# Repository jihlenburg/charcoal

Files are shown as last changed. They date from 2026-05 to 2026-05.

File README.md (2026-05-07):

# Aktivkohlefilter-Einsatz (Passivlüftung mit aktiven Absaugungen)

**Version: 1.1.6**. Der String steht im Script als `VERSION`-Konstante und
wird als Gravur auf den +Y-Flanschüberstand übernommen. Bei jedem Versionssprung
muss er gleichzeitig in `carbon_filter_build123d.py`, im README und am
git-Tag nachgezogen werden.

Parametrischer Filterkorb aus Grundkörper und Deckel für die Wohnungs­lüftung
mit Aktivkohle. Die Konstruktion ist für HP Multi Jet Fusion in **PA12**
ausgelegt (`HP 3D HR PA 12 enabled by Evonik` oder vergleichbar). PA11 ist
nach wie vor eine tolerantere Alternative, aber nicht mehr der Konstruktionsfall.

Quellcode: [`carbon_filter_build123d.py`](./carbon_filter_build123d.py) (build123d).

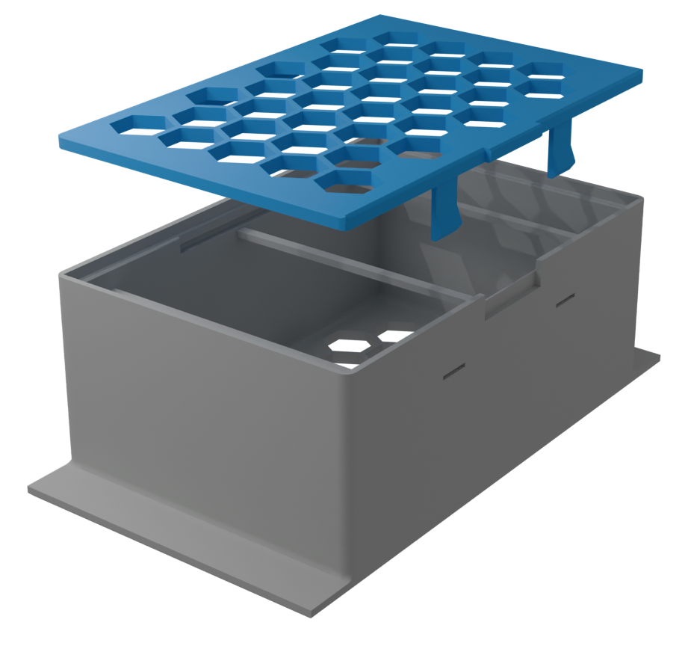
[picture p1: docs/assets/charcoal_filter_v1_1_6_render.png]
Exploded render of the filter cassette


Das README-Render entsteht über `./run render-readme` (Blender/Cycles, mit
VTK-Fallback, falls Blender fehlt).

## Konstruktionsprinzip

**Vertikaler Luftstrom durch den Filter.** Die Luft tritt durch das Hex-Gitter
auf der einen Z-Seite (Deckel) ein, durchströmt das Aktivkohlebett und
verlässt die Kassette durch das Hex-Gitter auf der anderen Z-Seite (Boden).
Im Skript-Koordinatensystem ist Z die Luftstromachse — eingebaut steht die
Kassette um 90° gekippt, sodass Z horizontal zur Schachttiefe wird.

### Befüllung (Kassette stehend, Deckel oben)

1. Finger in die mittige Freistellung an der Schnapper-Seite setzen und den
   Deckel am kleinen Zugsteg nach oben anheben. Die beiden Schnapper lösen
   sich dabei über ihre Auslöserampe selbsttätig; auf der Gegenseite hält die
   Hakenleiste den Deckel in ihrer Tasche und gibt damit die Öffnungs­seite vor
2. Filtervlies auf den Boden legen (3 mm, dichtet Hex gegen Granulatdurchfall)
3. Aktivkohlegranulat einfüllen (~29 mm Schüttung, ~72 g bei 450 kg/m³)
4. Zweites Filtervlies obenauf; die internen Anti-Bauch-Bars liegen 4.0 mm
   unter der Deckelunterseite, sodass ein 3-mm-Vlies mit ca. 1 mm Reserve
   zwischen Bars und Deckel passt
5. Deckel erst mit der Hakenleiste in die Gegentasche einsetzen, dann die
   Schnapper-Seite herunterdrücken bis beide Nasen hörbar einrasten

## Einbaukontext

Der Schacht am Fensterrahmen hat 70 mm harte Innenbreite (mit je ca. 5 mm
Schaumstoff an beiden Seiten → 80 mm weich), 100 mm harte Höhe und 100 mm
Tiefe. Luftrichtung: hinten → vorne, angetrieben von drei aktiven
Wohnungs­absaugungen (3 Fenster × 2 Schächte = 6 parallele Zuluftpfade).

**Einbaulage (wichtig)**: Die Kassette wird mit dem **Deckel nach hinten**
eingeschoben, der **Boden zeigt nach vorne** in die Wohnung. Gründe:

- Der Y-Flanschüberstand (je 10 mm oben und unten) ist der Fingergriff.
  Beim Ziehen kommt immer die gesamte Kassette mit — nie nur der Deckel.
- Der Luftstrom drückt den Deckel in seinen Sitz, nicht heraus.
- Der Flansch am Boden fungiert als **Einschub-Stopper und Fingergriff**.
  Er ragt **nur in Y-Richtung** (vertikal im Schacht) über den Körper
  hinaus — in X bleibt er auf Körperbreite, weil die harte Schachtbreite
  70 mm nicht überschritten werden darf. Flansch-Footprint: 65 × 115 mm vs.
  Schacht-Hartöffnung 70 × 100 mm — die je 10 mm-Überstände oben und unten
  fangen an der Schacht-Frontkante und geben gleichzeitig bequem Platz für
  Daumen/Zeigefinger. Die Kassette steht damit `floor = 2.2 mm` aus der
  Öffnung heraus — klar unter der 5-mm-Grenze.

### Abdichtung mit Moosgummi

Die Y-Flächen der Kassette — im Skript-Frame oben und unten — kontaktieren
im Schacht die **harten** oberen und unteren Schachtwände. Sie sind dafür
glatt und ohne Durchbrüche ausgeführt. Vor dem Einschub werden auf beide
Flächen **Moosgummistreifen** geklebt; beim Einschieben werden sie
zusammengepresst und dichten dadurch axial gegen Leckluft am Filterbett vorbei.

Auf der einen X-Fläche sitzen die Snap-Durchbrüche, gegenüber eine flache
Haken-Tasche im oberen Wandbereich. Beide X-Flächen drücken sich in den
seitlichen Schaumstoff und werden so durch den Schaum selbst abgedichtet.

## Geometrie

- Zwei Teile: Grundkörper (Trog mit integriertem Flansch + Boden) und Deckel
- Körper-Aussenmasse: **65 (X) × 95 (Y) × 40 (Z)** mm
- Bodenflansch: **65 × 115 × 2.2** mm (Z = 0 … 2.2) — nur in Y breiter als Körper
  (je 10 mm Überstand oben und unten als Stopper + Fingergriff)
- Wand 2.2 mm, Boden 2.2 mm, Deckel 2.5 mm
- Hex-Perforation identisch auf **Boden** und **Deckel** (Z-Flächen):
  10 mm flat-to-flat, 1.2 mm Stegbreite, 2.8 mm X-Randabstand und 4.0 mm
  Y-Randabstand → 36 Löcher pro Fläche, ~57 % Offenfläche
  (~31 cm² auf ~55 cm² Kavität)
- Rabbet-Sitz am oberen Rand, 1.0 mm Schulter, 2.5 mm tief
- Passungsspiel 0.30 mm pro Seite (MJF-Standard)
- Kein Fingerausschnitt am Boden — die 10 mm Y-Flansch-Überstände oben und
  unten dienen als Fingergriff (Daumen oben, Zeigefinger unten, ziehen)
- Aktivkohlebett-Tiefe: **29.3 mm** (= Z − Boden − Deckel − 2 × 3 mm Filtervlies)
- Drei interne Anti-Bauch-Bars verbinden die langen X-Wände bei
  `Y = -36, 0, +36 mm`. Je Bar: **2.2 mm** breit in Y, **1.4 mm** hoch in Z,
  quer über die Kavität. Lage: **Z = 32.1 … 33.5 mm**, damit zur
  Deckelunterseite bei `Z = 37.5 mm` ein **4.0 mm** Spalt für das obere
  3-mm-Filtervlies bleibt.

### Versionsgravur

Der `VERSION`-String aus dem Script wird als 0.6 mm tiefe Vertiefung
(Font-Size 5 mm) auf die **Apartment-seitige Fläche des +Y-Flansch­überstands**
graviert. Position: Z = 0 … 0.6 mm, vertikal zentriert auf der Mittellinie des
10 mm breiten Überstands. Die Stelle ist solid (keine Hex-Löcher, keine
Snap-Schlitze), in der Sichtlinie des Benutzers, und die 1.6 mm Restboden
unter der Gravur liegt komfortabel über dem MJF-Minimum von 1.0 mm.

Die Gravur-Ebene ist bewusst gespiegelt konstruiert (Plane mit `z_dir=-Z`
und `x_dir=-X`, sodass `y_dir=+Y` rechtshändig bleibt), damit der Text von
der Apartment-Seite aus korrekt lesbar ist — aus −Z-Blickrichtung wäre ein
Standard-Plane.XY-Sketch nämlich spiegelverkehrt dargestellt.

Beim Versionswechsel muss die `VERSION`-Konstante im Script-Header **und**
die Angabe oben im README synchron nachgezogen werden (plus git-Tag beim
Release).

### Deckel und Schnappverbindung

- Deckel 2.5 mm dick, Oberseite bündig mit der Trog-Oberkante
- Asymmetrische Verriegelung: **eine** passive Hakenleiste auf einer X-Seite,
  **zwei** Cantilever-Rastnasen auf der gegenüberliegenden X-Seite.
- Passive Hakenleiste: 34 mm lang, 3 mm Absenkung, als **einfache**
  Hakenleiste mit 2.1 mm Gesamttiefe, 1.0 mm starkem oberem Steg und einer
  0.35 mm über die Deckelkante nach außen gezogenen Nase. Die reale
  Überdeckung hinter der Trog-Innenwand steigt damit auf etwa **1.05 mm**.
  Sie greift in eine flache rechteckige Tasche in der Gegenseite. Die Tasche
  ist zweistufig: unten eine 1.35 mm tiefe Retentionstasche, oben nur ein
  0.55 mm tiefer Einführkanal. Dadurch bleibt über der unteren Tasche eine
  **0.80 mm** tiefe Material-Lippe, unter der die Haken-Nase sichtbar trägt.
  Außen bleiben etwa **0.30 mm** Taschenluft. Die äußerste Haken-Nase ist mit
  einer 0.2-mm-Fase entschärft.
- Keine passiven Eckfreistiche mehr: die `v1.1.0`-Reliefs haben auf den
  Druckteilen eine sichtbare Diagonalkante erzeugt. `v1.1.6` entfernt diese
  kosmetische Störkante wieder; die zweistufige Haken-Tasche bleibt im
  Baugruppen-Checker trotzdem kollisionsfrei.
- Rastnasen: 6 mm breit, 10.2 mm lang, 1.0 mm Armdicke, 1.1 mm
  Lippenüberstand, 1.5 mm Einführschräge, 0.4 mm Haltelänge, 2.8 mm
  Auslöserampe, 0.5 mm Armwurzel-Fillet.
- Auf der Schnapper-Seite sitzt mittig eine kleine Zuglippe; die Trogwand hat
  dort eine Freistellung, die bewusst noch 1.0 mm Restwand stehen lässt,
  sodass der Deckel nach dem Entriegeln gezielt angehoben werden kann.
- Vorteile:
  - Klare passive Halteseite statt bloßer Führung
  - Deutlich einfacher als ein tiefes verstecktes Haken-/Taschensystem
  - Toleranzfreundlicher als 4 aktive Schnapper
  - Reversibel mit **einer** Hebebewegung: Zuglippe anheben, Schnapper
    cammen selbsttätig frei, Deckel klappt an der Haken-Seite kontrolliert hoch

### Variantenvergleich

- **Nur Führungsleiste**: sehr einfach und für MJF gut druckbar, aber
  ohne passive Haltefunktion. Die Gegenseite positioniert nur, sie trägt
  keinen Aufwärtslastpfad.
- **Einfache Hakenleiste**: der beste Kompromiss. Ein echter Formschluss auf
  einer Seite, dabei aber nur eine flache, gut entpulverbare Tasche mit
  kleiner Überdeckung.
- **Tiefes Haken-/Taschensystem**: mechanisch eindeutig, aber unnötig komplex,
  toleranzempfindlicher und für diesen Anwendungsfall überdimensioniert.

### Öffnungsbewegung und Kraftfluss

Im geschlossenen Zustand greifen auf der Schnapper-Seite die beiden Rastlippen
über die Oberkante der Slots, und auf der Gegenseite sitzt die einfache
Hakenleiste mit etwa `1.1 mm` Überdeckung unter dem Taschendach. Ein
Aufwärtszug am Deckel verteilt sich deshalb nicht nur auf die Schnapper,
sondern wird als Moment zwischen Schnapper- und Hakenseite aufgenommen.

Das Öffnen beginnt an der mittigen Zuglippe auf der Schnapper-Seite. Die
Fingerkraft erzeugt dort ein Drehmoment um die passive Hakenseite, und die
oberen Auslöserampen der Schnapper laufen gegen die Slot-Kante. Aus dem
vertikalen Hub wird dadurch eine seitliche Arm-Auslenkung; die Reaktions­kraft
fließt vom Finger über den Deckel in die Schnapper und von dort in die
Trogwand der Slot-Seite.

Sobald die Schnapper ausgelöst haben, sind sie weitgehend lastfrei. Den Rest
des Öffnungsmoments übernimmt die passive Hakenseite: der Deckel klappt um
sie hoch, statt auf beiden Seiten gleichzeitig lose zu werden. Zum
vollständigen Abnehmen wird er nach dem Hochklappen leicht zur Schnapper-Seite
verschoben, sodass der passive Haken aus seiner Tasche frei kommt — erst dann
lässt er sich nach oben abheben.

### Öffnungskraft / Werkzeugfreiheit

Für die Rastarme wird der Deckel als rechteckiger Cantilever abgeschätzt.
Die reine Armsteifigkeit liefert die laterale Federkraft; die tatsächliche
Fingerkraft beim Öffnen sinkt durch die obere Auslöserampe:

```
F = 3 · E · I · δ / L³
I = b · t³ / 12
```

mit `b = 6 mm`, `t = 1 mm`, `L = 10.2 mm`, `δ = hook_protr + fit_clear = 1.4 mm`
und einem HP-PA12-Elastizitätsmodul von grob `E ≈ 1.65 … 2.20 GPa`
(JF 5200/5600-Datenblattband).

Ergebnis:

- laterale Federkraft pro Schnapper: **ca. 3.3 … 4.4 N**
- geschätzte Finger-Hebekraft gesamt: **ca. 3.3 … 4.4 N**
  für beide Schnapper zusammen, mit 2.8-mm-Auslöserampe und einer groben
  Reibannahme `μ ≈ 0.2`
- Maximale Randfaserdehnung: **≈ 2.02 %**

Damit ist die Bedienung realistisch **ohne Werkzeug** und mit einer einzigen
Fingerbewegung. Die Schnapper müssen nicht separat gedrückt werden; beim
Anheben an der Zuglippe fahren sie über die Auslöserampe selbst nach innen.

HPs Snap-Fit-Handbook gibt als grobe Faustregel eine zulässige Dehnung
unter `1/3` der Fließdehnung an. Mit HP-PA12 (`~9 … 11 %` Fließdehnung laut
5600-Datenblatt) liegt der Zielbereich damit bei `< 3.0 … 3.7 %`; die
aktuellen `~2.02 %` bleiben deutlich darunter. Bei nur wenigen Öffnungs­zyklen
pro Jahr ist das für PA12 weit plausibler als die ältere kurze 7-mm-Geometrie.

### Lokale FEM des Schnappers

Zur Balkenabschätzung kommt eine lokale 3D-FE-Analyse in
`fem/snap_fit_fem.py` dazu. Das Modell bildet **einen aktiven Schnapper** in
der aktuellen `v1.1.6`-Nasenform ab, belastet die reale Rastfläche mit
`1 N` in `+X` und skaliert die Antwort anschließend auf die nötige
Öffnungs-Auslenkung `hook_protr + fit_clear = 1.40 mm`.

Drei Vorbehalte zum Mitlesen:

- Es ist bewusst nur ein **lokales Submodell**, kein vollständiges
  Kontaktmodell aus Deckel, Trog und Gegenhaken.
- Die FE-Kraft fällt **konservativer** aus als die Balkenformel, weil die
  Last an der realen Rastfläche bei `z ≈ -8.5 mm` ansetzt, nicht am freien
  Armende.
- Der `0.5 mm`-Armradius an der Deckelwurzel ist in diesem ersten Modell
  noch nicht explizit vernetzt; die echte Spitzendehnung dürfte deshalb
  leicht niedriger liegen.

Aktueller Stand mit `mesh_size = 0.25 mm` und nominalem `E = 2150 MPa`:

- laterale Federsteifigkeit pro Schnapper: **~7.3 N/mm**
- nötige laterale Auslenkkraft pro Schnapper für `1.40 mm`: **~10.3 N**
- geschätzte Gesamt-Hebekraft zum Öffnen: **~8.0 … 10.6 N**
- maximale Hauptdehnung beim Öffnen: **~3.4 %**

Werkzeugloses Öffnen bleibt damit plausibel. Wiederholtes Öffnen liegt im
HP-`1/3`-Proxyband für PA12 (`< 3.0 … 3.7 %`), aber mit kleinerer Reserve,
als die reine Balkenformel vermuten lässt.

### Lokale FEM der passiven Hakenleiste

Für die passive Hakenleiste gibt es das Pendant-Modell `fem/hook_hold_fem.py`.
Es belastet den unteren Hakennasenbereich mit `1 N` nach unten, klemmt den
oberen Steg als Deckelanschluss ein und skaliert die lineare Elastizität bis
zum PA12-`1/3`-Proxyband hoch.

Aktueller Befund für `v1.1.6`:

- reale Überdeckung hinter der Trog-Innenwand: **1.05 mm**
- nötige bewusste `+X`-Verschiebung zum Aushängen: **~1.05 mm**
- äußere Taschenluft: **0.30 mm**
- Retentionslippe in der Trogwand: **0.80 mm** tiefer Materialüberhang
- oberer Hakensteg: **1.00 mm** stark, **34 mm²** Querschnitt
- vertikale lokale Steifigkeit der Hakenleiste: **~1027 N/mm**
- PA12-`1/3`-Proxy-Haltekraft strukturell: **~174 … 213 N**

Interpretation: Nicht die PA12-Festigkeit der Hakenleiste war der begrenzende
Faktor, sondern ihre Geometrie. `v1.1.3` hatte real nur etwa `0.70 mm`
Untergriff und einen mit `0.40 mm` zu dünnen oberen Hakensteg. Ab `v1.1.5`
ist der Untergriff vergrößert, der Haken selbst sauberer druckbar und in der
Trogwand sitzt eine sichtbare Retentionslippe.

### Innenaufbau (Luftweg-Richtung: Deckel → Boden)

```
Hex-Deckel → 3 mm Filtervlies → Anti-Bauch-Bars / Aktivkohlebett (~29 mm) → 3 mm Filtervlies → Hex-Boden
```

Das Bett sitzt zwischen zwei Vlieslagen; sie halten die Pellets zurück und
fangen gleichzeitig Staub ab. Die Anti-Bauch-Bars liegen unter dem oberen
Vlies und halten die langen Seitenwände beim Befüllen davon ab, sich nach
außen zu biegen.

## Nutzung

Die Python-Umgebung wird über `./run` automatisch als lokale `.venv/`
angelegt und aus `requirements.txt` aktualisiert, sobald sich die
Abhängigkeiten ändern. Der Wrapper wählt automatisch eine kompatible
Python-Version im Bereich 3.9–3.12, weil die CAD/OCP-Native-Wheels nicht für
jede neueste Python-Version verfügbar sind:

```bash
./run setup
```

1. VSCode öffnen, Command Palette → „OCP CAD Viewer: Open Viewer"
2. `./run cad` ausführen
3. Viewer-Panel: Maus zum Drehen, Scroll zum Zoomen

Datei speichern triggert Live-Reload im Viewer. Beim Ausführen werden
automatisch die Exporte in `output/STEP/` (für STEP) und `output/STL/`
(für STL) geschrieben — je eine `trough.*` und `lid.*` Datei.

`EXPLODED = True` hebt den Deckel 30 mm über den Trog; für die
Zusammenbau-Ansicht auf `False` setzen.

Für manuelle Python-/Pip-Kommandos innerhalb derselben Umgebung:

```bash
./run python --version
./run pip list
./run shell
```

### Konsistenz-Check Script ↔ README

Die geometrischen Konstanten (Außenmaße, Wandstärken, Hex-Raster,
Anti-Bauch-Bars, Snap- und Hook-Maße) und der `VERSION`-String stehen doppelt
im Repo: einmal als Variablen im Script, einmal als Prosa- und Tabellenwerte
in diesem README. Damit beide nicht auseinanderlaufen, gleicht sie ein
Sync-Checker laufend ab:

```bash
./run check
```

Der Checker parst `carbon_filter_build123d.py` per AST, formatiert jeden
registrierten Wert so, wie er im README erscheinen würde (mit
Trailing-Zero-Toleranz, also `1.0` ↔ `1`), und sucht ihn als regulären
Ausdruck im README — auch über Soft-Wrap-Zeilenumbrüche hinweg. Vor jeder
Geometrie- oder Versions­änderung sollte der Lauf grün durchgehen.

### DFM-Strict-Modus

`try_fillet` und `try_chamfer` werden im Build an genau den Stellen mit
`strict=True` aufgerufen, die in der DFM-Tabelle den Status ✓ („vollständig
akzeptiert") tragen. Verliert eine dieser Stellen Kanten an OCCT, bricht
`./run cad` mit einer FATAL-Meldung ab: die README-Garantie wäre dann
verletzt und der Druck nicht mehr vertrauenswürdig. Stellen, die in der
Tabelle ohnehin als OCCT-Grenzfall geführt werden (die `flange corner`-Schelfs
und die `lid bot perim`-Innenkanten), bleiben best-effort und tauchen
einfach als „skipped" in der Zusammenfassung auf. Am Ende der Build-Phase
schreibt das Script eine kompakte Übersicht aller DFM-Operationen ins Log.

### FEM ausführen

Die lokale Schnapper-Simulation läuft separat vom CAD-Export:

```bash
./run fem-snap
./run fem-snap --vtk output/FEM/snap_fit_v1_1_6.vtu
./run fem-snap --json output/FEM/snap_fit_v1_1_6.json
./run fem-hook
./run fem-hook --json output/FEM/hook_hold_v1_1_6.json
./run fem-bulge
./run fem-bulge --json output/FEM/trough_bulge_v1_1_6.json \
  --vtk-dir output/FEM/vtk --plot-dir output/FEM/plots
```

#### FEM-Baseline-Vergleich

Jeder Solver schreibt eine JSON-Datei mit den wichtigsten Skalaren:
Steifigkeiten, Haltekräfte, Maximaldehnungen, Penetrationen. Diese Werte
werden gegen eine eingecheckte Baseline unter `output/FEM/baseline/` geprüft,
damit eine Geometrie- oder Solver-Änderung das Antwortverhalten nicht
unbemerkt verschiebt:

```bash
./run fem-diff                    # nur Vergleich, kein Schreiben
./run fem-diff --update-baseline  # aktuelle Ergebnisse als neue Referenz übernehmen
```

Die Default-Toleranz liegt bewusst lose bei ±15 % relativ. Die
PA12-Modul-Unsicherheit beträgt schon auf Materialebene ±15 %; engere
Schranken würden nur Fehlalarme produzieren. Felder, die physikalisch exakt
sein müssen (Penetrations-Punkte, Feasibility-Flags), werden dagegen hart
verglichen. Eine bewusst akzeptierte Designänderung wird mit
`--update-baseline` als neue Referenz übernommen. Die Baseline-Dateien
heißen absichtlich versionsfrei (`snap_fit.json` statt `snap_fit_v1_1_6.json`),
damit sie ein Versionssprung nicht verwaisen lässt.

`--vtk` und `--json` legen Zielverzeichnisse wie `output/FEM/` bei Bedarf
automatisch an.

Das `.vtu` lässt sich direkt in ParaView öffnen. Gespeichert werden:

- nodale Verschiebungen in mm
- maximale/minimale Hauptdehnung pro Tetraeder
- von-Mises-Dehnungsproxy pro Tetraeder

### Trogwand-Bauchung beim Befüllen

Für die beobachtete Bauchung der langen Trogwände gibt es
`fem/trough_bulge_fem.py`. Das Script bildet den Trog als vereinfachtes
lineares PA12-Solidmodell ab, belastet die Innenflächen der langen X-Wände
mit gleichförmigem seitlichem Granulatdruck und vergleicht den früheren
Plain-Trog gegen den aktuellen Trog mit internen Anti-Bauch-Bars.

Aktueller Befund für `v1.1.6` bei `5 kPa` Seitenlast:

- Plain-Trog ohne Bars: **0.083 mm** maximale Ausbuchtung
- aktueller Trog mit 3 internen Bars: **0.023 mm** maximale Ausbuchtung
- Druck für 1.0 mm Ausbuchtung: **60.5 kPa → 217.8 kPa**
- maximale Hauptdehnung bleibt bei beiden Varianten deutlich unter dem
  konservativen PA12-`1/3`-Proxy

Die erzeugten Heatmaps liegen unter `output/FEM/plots/`, die optionalen
ParaView-Felder unter `output/FEM/vtk/`.

### Vollbaugruppen-Kontakt / Kippmontage

Für die Baugruppenprüfung gibt es zusätzlich
`fem/lid_trough_assembly.py`. Das Script lädt **den vollständigen Deckel**
und **den vollständigen Trog** als STL, legt eine plausible
Hook-first-Bewegungsfamilie um die passive Hakenlinie an und bewertet
den Deckel dann über Signed-Distance gegen das Trogmaterial.

Lauf:

```bash
./run fem-assembly
./run fem-assembly --json output/FEM/lid_trough_assembly_v1_1_6.json
```

Auch hier wird das Zielverzeichnis der JSON-Datei bei Bedarf automatisch
angelegt.

Aktueller Befund für `v1.1.6`:

- beste gefundene Hook-first-Kipplage im Suchraum: **`-10°`**, `dx = +0.40 mm`,
  `dz = +1.20 mm`
- eingehakte Kipplage: **kollisionsfrei** (`max penetration = -0.163 mm`)
- vertikale Einfädelbahn bei dieser Kipplage: **kollisionsfrei**
- Schließbahn in die Endlage: **ohne harte Kollision**;
  verbleibende Interferenz liegt nur an den aktiven Schnappern
  (`snap ~0.94 mm`) und ist dort die beabsichtigte elastische Einfederung
- harte Restpenetration außerhalb der Schnapper: **0 Punkte**

Interpretation:

- Die passive Hakenleiste funktioniert jetzt auch als **praktisch nutzbare
  Kipp-Einhakeachse**, weil die flache Haken-Tasche bis an die
  Rabbet-Unterseite als Einführkanal geöffnet ist.
- Die Hook-first-Montage ist damit geometrisch plausibel:
  erst passive Seite einhängen, dann herunterrotieren, zuletzt die
  +X-Schnapperseite eindrücken.
- Kritisch bleibt nur noch die beabsichtigte Schnapper-Einfederung beim
  finalen Schließen, nicht mehr eine harte Baugruppen-Kollision.
- Die entfernten passiven Eckfreistiche und die neuen internen Anti-Bauch-Bars
  erzeugen im geprüften Suchraum keine harte Baugruppen-Kollision.

### Montagezeichnungen

Die Montagefolge wird zusätzlich als SVG ausgegeben:

```bash
./run drawings
```

Das Script legt `output/assembly/` bei Bedarf automatisch an.

Erzeugte Dateien:

- `output/assembly/lid_trough_assembly_sequence_v1_1_6.svg`
- `output/assembly/lid_trough_snap_detail_v1_1_6.svg`

Das Sequenzblatt zeigt die Hook-first-Montage in drei Schritten, das
Detailblatt die elastische Einfederung der aktiven Rastnase beim finalen
Eindrücken.

### Mesh-Heal für STL-Export (pymeshfix)

Die OCCT-STL-Tessellation hinterlässt an Tangenten­nähten von
Fillets/Chamfers teilweise offene Randloops und Selbstdurchdringungen.
Der Export schreibt deshalb zuerst weiterhin STEP und eine direkte OCCT-STL,
remesht die STEP-Dateien dann mit Gmsh zurück zu STL und lässt anschließend
`pymeshfix` als finalen Topologie-Heal laufen. Ist `pymeshfix` nicht
installiert, bleibt der Gmsh-remeshte STL-Stand erhalten; nur der finale
Selbstdurchdringungs-Clean wird übersprungen.

Verhalten:

- **trough.stl**: STEP→Gmsh ergibt eine wasserdichte STL; `pymeshfix` reduziert
  danach 13 Selbstdurchdringungen auf 0, bei praktisch unverändertem Volumen
  (`34.88 → 34.89 cm³`).
- **lid.stl**: STEP→Gmsh mit gröberem Lid-Remesh (`0.4 … 1.0 mm`) ergibt
  eine wasserdichte, winding-konsistente STL; `pymeshfix` überspringt den
  finalen Clean, weil bereits 0 Randloops und 0 Selbstdurchdringungen
  gefunden werden (`6.76 cm³`).

**Upload-Empfehlung** (Stand `v1.1.6`):

- `trough.stl` und `lid.stl` sind die aktuellen STL-Upload-Kandidaten
  (0 Randloops, 0 gemeldete Selbstdurchdringungen).
- `trough.step` und `lid.step` bleiben als BRep-Fallbacks verfügbar.

Optional: `./run --with-heal setup` installiert zusätzlich
`requirements-heal.txt` (`pymeshfix`). Danach nutzt `./run cad` den
finalen Heal-Schritt automatisch; ohne diese optionale Abhängigkeit läuft der
Export weiterhin durch und protokolliert nur den übersprungenen
`pymeshfix`-Clean.

## MJF-Optimierungen

### Grundparameter

| Bereich | Wert | Grund |
|---|---|---|
| Wandstärke | 2.2 mm | Nach Rabbet-Schulter 1.2 mm Restwand → oberhalb MJF-Minimum (1.0 mm) |
| Bodenstärke | 2.2 mm | Gleichwertige Struktursteifigkeit, gleichzeitig Flansch-Dicke |
| Passungsspiel `fit_clear` | 0.30 mm | MJF-typischer Toleranzbereich ±0.3 mm |
| Hex-Raster | 10 mm flats, 1.2 mm Web, 2.8 mm X-Margin, 4.0 mm Y-Margin | Grösseres Raster = weniger Stegen/Fläche, besseres Entpulvern, Stege trotzdem deutlich über MJF-Minimum |
| Anti-Bauch-Bars | 3 interne Querbars, 2.2 × 1.4 mm, 4.0 mm unter Deckelunterseite | Hält die langen X-Wände beim Befüllen gegen Ausbeulen zusammen, bleibt komplett innerhalb des 65-mm-Aussenmasses und lässt Platz für 3-mm-Obervlies |
| Eckenfillet Körper | 2.0 mm | Bessere Oberfläche; Flansch-Y-Kanten bleiben scharf (Stopperfunktion) |
| Armwurzel-Fillet | 0.5 mm | Kerbspannungsreduktion → Dauerfestigkeit des Snap-Arms |
| Snap-Mechanik | 1 einfache Hakenleiste + 2 selbstlösende Schnapper | echte passive Halte-Seite, aber einfach und MJF-freundlich, nur zwei elastische Stellen, einhändig entriegelbar |
| Entpulvern | Hex oben + unten durchgehend | Pulver rieselt frei durch die Kassette |

### DFM im Detail: 90°-Kanten-Rundungen und -Fasen

MJF-PA12 prüft keine scharfen Kanten in der Druckbarkeit — der Prozess druckt
Kanten so scharf wie das Laserscanfeld. Rundungen und Fasen werden eingesetzt,
um **(a)** Spannungskonzentrationen an konkaven Innenkanten zu reduzieren,
**(b)** Anfassbarkeit/Taktilität zu verbessern, **(c)** das Entpulvern zu
erleichtern und **(d)** Risiken beim Handling (Absplittern, scharfe Kanten)
zu vermeiden.

| Kante / Feature | Operation | Radius | Begründung | Status |
|---|---|---|---|---|
| Körper-Senkrechtkanten (4 vertikale X/Y-Ecken) | Fillet | 2.0 mm | Haupt-Oberflächenqualität, Hand-Kontaktkanten | ✓ |
| Flansch-Unterseite (4 Aussenkanten bei Z=0) | Chamfer | 0.8 mm | Fingergriff-Seite, verhindert Absplittern beim Einschub, keine scharfe Kante gegen Finger | ✓ |
| Flansch-Y-Step (2 gerade Kanten bei Z=floor, Y=±size_y/2) | Fillet | 1.0 mm | Konkaver 90°-Innenwinkel zwischen Körper-Seitenwand und Flansch-Oberseite — klassische Kerbspannungsstelle beim Einschieben | ✓ |
| Flansch-Eckenschelfs (4 Bogenkanten bei Z=floor, Körperecke ∩ Flansch-Oberseite) | Chamfer-Fallback | — | Sitzen zwischen der zylindrischen 2-mm-Körperecken­fillet und der ebenen Flansch-Oberseite → OCCT verweigert Fillet UND Chamfer (Tangentenkonflikt). Kosmetisch, ~2×2 mm, nicht lasttragend, MJF druckt sie sauber | Offen (akzeptiert) |
| Kavitäts-Bodeninnenkanten (4 Kanten bei Z=floor zwischen Bodenplatte und Kavitätswänden) | Fillet | 1.0 mm | Konkave Innenecken — Kerbspannung bei Flexion der Bodenplatte durch Kohlebett-Masse. Ausserdem: Pulver sammelt sich in scharfen 90°-Ecken, Verrundung hilft beim Entpulvern | ✓ |
| Rabbet-Schulterkanten (konkav/konvex bei Z=size_z−rabbet_depth) | Fillet | 0.3 mm | Kleine Rundung reduziert den abrupten Absatz ohne die Auflageflächen (shelf_w=1.0 mm) nennenswert zu verkleinern (verbleibend ≥0.7 mm Kontakt für Deckel) | ✓ |
| Snap-Armwurzel (Übergang Arm → Deckelunterseite) | Fillet | 0.5 mm | Klassische Cantilever-Kerbe — ohne Radius wäre das die erste Rissstelle bei Wiederholbelastung. 0.5 mm bringt Spannungskonzentrationsfaktor von ~3 auf <1.5 | ✓ |
| Deckel-Vertikalecken (4 Kanten entlang Z) | Fillet | 1.0 mm | Handling, konsistent mit Körperecken­fillet (2.0 mm wäre am kleineren Deckel-Footprint zu dominant) | ✓ |
| Deckel-Oberkante (4 Aussenkanten bei Z=size_z) | Chamfer | 0.5 mm | Sichtseite von oben, verhindert Absplittern und scharfe Kante unter dem Fingerdruck zum Öffnen | ✓ |
| Deckel-Unterkante (äussere Kanten bei Z=size_z−lid_thk inkl. Zuglippe) | Chamfer | 0.2 mm / 0.4 mm | Rabbet-Einführschräge für den Einbau; die kleine Zuglippe bekommt separat 0.4 mm. OCCT akzeptiert wegen der +X-Snapwurzel und der passiven Hakenleiste nicht alle Kanten, aktuell **1/5** gefundene Unterkanten mit 0.2 mm. Rest bleibt lokal scharf — MJF druckt sauber | Teilweise (akzeptiert) |

### Per-Kanten-Fallback für OCCT-Grenzfälle

Die Fillet/Chamfer-Operationen im Script nutzen eine `try_fillet` /
`try_chamfer`-Hilfsfunktion mit zweistufigem Fallback:

1. **Batch-Versuch**: alle selektierten Kanten auf einmal runden/fasen —
   schnell und konsistent, wenn die Geometrie es erlaubt.
2. **Per-Kanten-Versuch** bei Fehler: jede Kante einzeln; Fehler einzelner
   Kanten werden auf STDOUT protokolliert und übersprungen.

Grund: build123d/OCCT wirft eine Exception für den **gesamten** Batch, sobald
**eine einzige** Kante den gewünschten Radius nicht akzeptiert (typischer­weise
wegen Tangentenkonflikten mit anderen Radien/Zylinderflächen). Der Fallback
rettet die übrigen Kanten und gibt Diagnose aus, statt die komplette
DFM-Verbesserung zu verlieren.

### Konvex vs. konkav — Warum unterschiedliche Werte

- **Konvex/Aussen-Kanten** (Flansch-Unterseite, Körperecken): Chamfer 0.5–0.8
  mm oder Fillet 2.0 mm. Hauptzweck: Handling, Oberflächenqualität, keine
  scharfen Kanten gegen Finger oder angrenzende Flächen.
- **Konkav/Innen-Kanten** (Flansch-Step, Kavitäts-Boden, Armwurzel): Fillet
  0.3–1.0 mm. Hauptzweck: Kerbspannungsreduktion. Ein konkaver 90°-Winkel
  hat theoretisch einen unendlichen Spannungskonzentrationsfaktor; selbst
  kleine Rundungen (~10 % der Wandstärke) bringen ihn auf <2.

### Kein Powder-Trap

Alle Ausfräsungen (Kavität, Rabbet, Hex, Snap-Schlitze, flache Haken-Tasche,
Zuglippen-Freistellung) sind zur Aussenwelt bzw. nach oben geöffnet. Die
Anti-Bauch-Bars sind einfache offene Querstege, keine geschlossenen Taschen.
Die Hex-Bohrungen im Boden und Deckel sind deckungsgleich, sodass Pulver
während des Entpulverns frei hindurchfallen kann. Keine der Fillet- oder
Chamfer-Operationen schafft geschlossene Taschen.

### Druckorientierung (Empfehlung fürs Bureau)

- **Snap-Arme parallel zu den Pulverschichten** legen (Biegerichtung
  parallel zur Schichtebene). MJF ist nahezu isotrop (Z-Richtung ~5–10 %
  schwächer), aber beim 1-mm-Arm mit zyklischer Biegebelastung zählt jedes
  Prozent.
- **Flansch möglichst plan** (Z-Ebene parallel zur Baureise) → gleichmässige
  Flächenqualität auf den Dichtflächen.
- Wenn beides nicht gleichzeitig möglich ist: Priorität auf den Snap-Armen.

## Tiefenauslegung (`size_z` — Luftstromrichtung)

Kompromiss zwischen Kohlekapazität und Druckverlust durch die aktiven
Absaugungen. Nutzbarer Bettquerschnitt `cavity_x × cavity_y ≈ 60.6 × 90.6 ≈
55 cm²`, 6 parallele Pfade.

Druckverlust im AC-Granulatbett (Ergun, 3-mm-Pellets, ε ≈ 0.4):

| Face velocity | ΔP/mm Bett |
|---|---|
| 0.5 m/s | ~2.5 Pa |
| 1.0 m/s | ~8 Pa |
| 1.5 m/s | ~17 Pa |

Bei 40 mm `size_z` ergibt sich ein Kohlebett von 29.3 mm, Kapazität ~72 g pro
Kassette bei Schüttdichte ~450 kg/m³ → ~425 g gesamt über 6 Kassetten.
Erwartete Standzeit in normaler Wohnluft: ~6 Monate. ΔP bei realistischem
Arbeitspunkt (~0.5 m/s) ca. 50–80 Pa — verträglich mit
Bad-/Küchenabsaugungen (typisch 40–100 Pa statisch).

Tieferes Bett (45–55 mm) ist optional machbar, falls stärkere Absaugungen
vorhanden sind und längere Wechselintervalle gewünscht.

### Snap-Belastungs-Check

Beim Entriegeln biegt sich der Arm um `hook_protr + fit_clear = 1.40 mm`.
Maximale Randfaserdehnung in einem Cantilever:

```
ε = 3 · t · δ / (2 · L²) = 3 · 1.0 · 1.40 / (2 · 10.2²) ≈ 2.02 %
```

HP-PA12 Yield liegt laut aktuellem Datenblatt bei grob `9 … 11 %`. Das
HP-Handbook empfiehlt für Snap-Fits als Näherung `< 1/3` davon, also
`< 3.0 … 3.7 %`. `2.02 %` liegt darunter. Das Script gibt den Wert beim Lauf
zusammen mit Kraftabschätzung und PA12-Band auf STDOUT aus.

Die lokale FE-Analyse liefert konservativer **~3.4 % maximale Hauptdehnung**.
Das bleibt ebenfalls noch im HP-Proxyband, liegt aber mit bewusst kleiner
Reserve in Richtung Oberkante. Genau deshalb ist die FE hier wertvoller als
die reine Cantilever-Formel: sie setzt die Last an der realen Rastfläche und
nicht am freien Armende an.

## Materialwahl PA12 vs. PA11

Lastprofil: rund 10 Öffnungs-/Schliesszyklen in fünf Jahren, reine
Innenraumluft, ständiger Kontakt mit Aktivkohle.

**PA12 ist die aktuelle Zielgeometrie.** Längere Schnapparme, grössere
Rastüberdeckung und eine kräftigere passive Hakenleiste sind genau so
gewählt, dass das Bauteil sich auch in HP-PA12 wiederholt und werkzeugfrei
bedienen lässt. Dazu kommt das praktische Argument: PA12 ist beim
Druckdienstleister Standard, günstig und für dieses Lastprofil ausreichend,
solange die Geometrie nicht zur älteren kurzen 7-mm-Snap-Version
zurückkehrt.

**PA11 ist die robustere Snap-Fit-Wahl** und lohnt sich, sobald ein
Dienstleister es ohne Aufpreis druckt oder die Kassette deutlich öfter
geöffnet werden soll. Damit hat sich die Rolle umgedreht: PA11 ist heute
die ruhige Reserve, nicht mehr der Default.

**Druckorientierung** (falls angebbar): Snap-Arm-Biegerichtung parallel zu
den Pulverschichten legen, nicht senkrecht. MJF ist nahezu isotrop, aber
der Effekt ist in Grenzfällen messbar.

**Entpulverung**: Die Hex-Raster auf Boden und Deckel sind durchgehend, das
Gehäuse hat keine geschlossenen Taschen. Pulver rieselt frei durch die Kassette
und durch die Snap-Schlitze.

## Lizenz

Das Projekt nutzt bewusst zwei verschiedene Lizenzen — je nachdem, ob ein
Artefakt eher als Hardware-Design oder eher als Software einzuordnen ist:

- **Hardware-Design, CAD-/STEP-/STL-/SVG-Ausgaben, FEM-Ausgaben und
  Designdokumentation**: CERN Open Hardware Licence Version 2 — Strongly
  Reciprocal (`CERN-OHL-S-2.0`)
- **Software-Scripte und Tooling**: GNU Affero General Public License v3.0
  or later (`AGPL-3.0-or-later`)

`carbon_filter_build123d.py` ist beides gleichzeitig: parametrische CAD-Quelle
des physischen Produkts und ausführbares Python-Script. Sie steht deshalb als
Hardware-Design-Quelle unter `CERN-OHL-S-2.0` und, soweit sie als Software
behandelt wird, zusätzlich unter `AGPL-3.0-or-later`.

Der kurze Projekt-Lizenzhinweis liegt in `LICENSE`; die vollständigen
Lizenztexte stehen unter `LICENSES/CERN-OHL-S-2.0.txt` und
`LICENSES/AGPL-3.0-or-later.txt`.

## Parameter im Script

Alle Masse stehen als benannte Variablen am Dateianfang und sind über
Kommentare erklärt. Änderung → Datei speichern → ocp-vscode-Viewer reloadet;
Script re-exportiert STEP/STL.

## Dateien

- `run` — legt `.venv/` automatisch an, installiert Pip-Abhängigkeiten und
  startet CAD-/FEM-/Zeichnungs-Kommandos
- `LICENSE` — kurzer Projekt-Lizenzhinweis mit Scope-Aufteilung
- `LICENSES/` — vollständige Lizenztexte für CERN-OHL-S-2.0 und AGPL-3.0-or-later
- `requirements.txt` — Kernabhängigkeiten für CAD, Viewer, FEM und
  Baugruppenprüfung
- `requirements-heal.txt` — optionale STL-Heal-Abhängigkeit `pymeshfix`
- `carbon_filter_build123d.py` — build123d-Script mit ocp-vscode-Viewer
- `fem/snap_fit_fem.py` — lokale 3D-FEM für den aktiven Schnapper
- `fem/hook_hold_fem.py` — lokale 3D-FEM und Geometriecheck für die passive
  Hakenleiste
- `fem/trough_bulge_fem.py` — lineare FEM für Trogwand-Ausbeulung beim
  Befüllen und Heatmap-/VTK-Ausgabe
- `fem/lid_trough_assembly.py` — Vollbaugruppen-Kontakt und Kippmontage-Check
- `fem/assembly_sequence_svg.py` — erzeugt SVG-Montagezeichnungen
- `scripts/check_readme_sync.py` — `./run check`: prüft Geometrie- und
  Versions-Konstanten zwischen Script und README
- `scripts/fem_baseline_diff.py` — `./run fem-diff`: vergleicht die FEM-JSONs
  gegen `output/FEM/baseline/` mit `--update-baseline` zum Promoten
- `scripts/render_readme_image.py` — Blender/VTK-Rendering des Hero-Bilds
- `output/FEM/baseline/` — eingecheckte FEM-Referenzergebnisse für `fem-diff`
- `README.md` — dieses Dokument
- `CLAUDE.md` — Arbeitsanweisungen für Claude in diesem Repo
- `TODO.md` — offene Aufgaben
- `LOGBOOK.md` — Änderungs- und Entscheidungsprotokoll

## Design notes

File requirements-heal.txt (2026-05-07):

# Optional STL repair dependency used by carbon_filter_build123d.py.
# Kept separate so the normal CAD/FEM environment is not blocked by
# pymeshfix/VTK installation issues.
pymeshfix==0.18.1

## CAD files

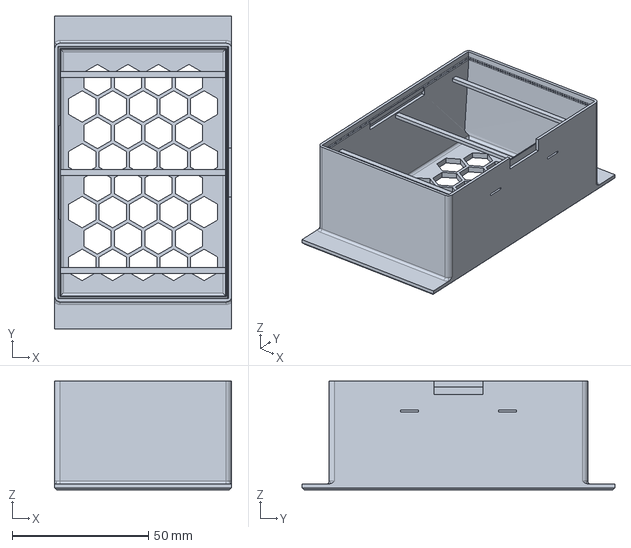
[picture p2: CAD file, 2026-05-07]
output/STEP/trough.step
65.1 x 115.0 x 40.0 mm

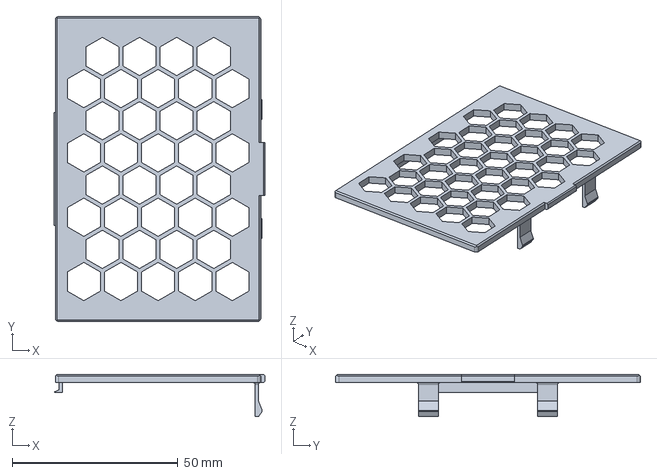
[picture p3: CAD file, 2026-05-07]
output/STEP/lid.step
63.6 x 92.0 x 12.7 mm

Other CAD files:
output/STL/lid.stl
output/STL/trough.stl

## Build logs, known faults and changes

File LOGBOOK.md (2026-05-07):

# Logbuch

Chronologisches Protokoll der Design- und Toolchain-Entscheidungen.

## 2026-05-07

### Toolchain-Härtung: README-Sync, DFM-Alarme, FEM-Baseline-Diff, Pinning

Bisher hat der Repo-Workflow auf Selbstdisziplin gesetzt: Geometrie­konstanten
und `VERSION` mussten zwischen `carbon_filter_build123d.py` und `README.md`
manuell synchron gehalten werden, `try_fillet`/`try_chamfer` haben fehlende
Kanten leise auf STDOUT protokolliert, und FEM-Resultate wurden zwar als JSON
nach `output/FEM/` geschrieben, aber nicht gegen einen Referenzstand
verglichen. Bei einem Repo, dessen „Deploy" ein bezahlter Druck beim Bureau
ist, sind stille Regressionen die teuerste Fehlerklasse — deshalb diese
Toolchain-Härtung.

Hinzugefügt:

- `scripts/check_readme_sync.py` (`./run check`): AST-parst Modul-Konstanten
  aus dem CAD-Script und prüft pro Parameter eine Liste regulärer Ausdrücke
  gegen `README.md`. Trägt Trailing-Zero-Toleranz (`1.0` ↔ `1`) und
  Whitespace-tolerantes Matching (für deutschen Soft-Wrap wie
  `1.1 mm\n  Lippenüberstand`). Aktuelle Abdeckung: 35 Sync-Punkte
  (VERSION, Außenmaße, Wandstärken, Hex-Raster, Anti-Bauch-Bars, Snap- und
  Hook-Geometrie, Gravur).
- `scripts/fem_baseline_diff.py` (`./run fem-diff`): vergleicht die
  versionierten FEM-Outputs (`<solver>_v1_1_6.json`) gegen unversionierte
  Baselines unter `output/FEM/baseline/<solver>.json` mit feldweise
  konfigurierbaren Toleranzen (`rel`, `abs`, `exact`). Default-Toleranz
  ±15 % relativ — bewusst lose, weil PA12-Modul-Unsicherheit bereits
  ±15 % beträgt und engere Schranken unecht alarmieren würden. Penetration-
  Counts und Feasibility-Flags sind exakt geprüft. `--update-baseline`
  promotet die aktuelle Lage zur neuen Referenz nach einer bewussten
  Designänderung.
- DFM-Alarme in `try_fillet`/`try_chamfer`: neuer `strict=True`-Schalter
  pro Aufruf, neuer `_dfm_log` und ein `_print_dfm_summary()` am Ende des
  Build-Phase. Sites, die laut README-DFM-Tabelle vollständig akzeptiert
  werden müssen (`flange bottom`, `flange step`, `cavity floor`, `rabbet`,
  `lid top perim`, `lid corner`), sind als `strict=True` markiert; der Lauf
  bricht hart ab, sobald OCCT dort eine Kante verliert. Bekannt
  problematische Stellen aus der DFM-Tabelle (`flange corner`-Schelfs,
  `lid bot perim`) bleiben best-effort.
- `requirements.txt` und `requirements-heal.txt` exakt gepinnt
  (`build123d==0.10.0`, `cadquery-ocp==7.8.1.1.post1`,
  `ocp_vscode==3.3.4`, …). OCCT-Minor-Versionen ändern Fillet-Akzeptanz
  still — der gedruckte Stand ist nur reproduzierbar, solange diese Pins
  halten.
- `.gitignore` entrümpelt (doppelter `.DS_Store`-Eintrag entfernt).

Validierung:

- `./run check`: 35/35 Parameter im Sync.
- `./run cad`: DFM-Tabelle zeigt 6 strict / 5 best-effort Sites; alle strict
  Sites bei 100 %; bekannt versagende Sites mit dokumentierten Skips.
  Negativtest mit temporär `strict=True` auf `flange corner`: korrekt
  abgebrochen mit FATAL-Meldung und `✗`-Markierung in der Tabelle.
- `./run fem-diff`: 22/22 Felder innerhalb der Schwellen gegen die initialen
  Baselines (mit `--update-baseline` aus den aktuellen Outputs erzeugt).
- `compare()`-Modi (`rel`/`abs`/`exact`) gegen synthetische Werte einzeln
  verifiziert.

Entscheidungen / verworfene Alternativen:

- Baselines unversioniert (`baseline/snap_fit.json`) statt versionsstempel
  (`baseline/snap_fit_v1_1_6.json`): so bleiben sie über Versions-Bumps
  gültig, statt zu verwaisen. Promotion via expliziten
  `--update-baseline`-Schritt.
- Sync-Checker arbeitet regex-basiert auf der bestehenden README-Prosa, statt
  die README aus den Konstanten zu generieren — die deutsche Erzählstruktur
  ist schwer maschinell zu rekonstruieren, und die geringe Änderungs­frequenz
  rechtfertigt die Asymmetrie nicht.
- DFM-Alarme als `strict`-Flag pro Aufruf, nicht als globale Mindest-Edge-
  Counts: die Call-Site-Annotation entspricht direkt der README-DFM-Tabelle
  („Status: ✓" vs. „Akzeptiert"), und neue Aufrufe erben sicher das
  best-effort-Default.

### Lizenzierung auf Hardware/Software-Split umgestellt

Der initiale GitHub-`LICENSE`-Stand war AGPLv3. Das ist für die Python-Tools
vertretbar, aber für CAD-/STEP-/STL-Dateien und daraus gedruckte Produkte
missverständlich. Das Repo wurde deshalb auf eine explizite Scope-Aufteilung
umgestellt:

- Hardware-Design-Source, generierte CAD-/Print-/FEM-Artefakte und
  Designdokumentation: `CERN-OHL-S-2.0`
- Software-Scripte und Tooling: `AGPL-3.0-or-later`
- `carbon_filter_build123d.py`: Hardware-Design-Source unter
  `CERN-OHL-S-2.0`; soweit als Software behandelt zusätzlich
  `AGPL-3.0-or-later`

Die vollständigen Lizenztexte liegen unter `LICENSES/`; der Root-`LICENSE`
ist jetzt ein kurzer Projekt-Lizenzhinweis mit Scope-Abgrenzung. Die
Python-/Shell-Scripte tragen SPDX-Identifier.

### Body auf 95 mm, Hexgrid erweitert und Anti-Bauch-Bars ergänzt, Release-Kandidat v1.1.6

Nach Rückmeldung vom Druckmuster wurde die verfügbare Schachthöhe besser
genutzt und gleichzeitig die beim Befüllen beobachtete Bauchung der langen
Trogwände adressiert. Außen darf wegen des engen Lüftungsschachts nichts
auftragen; daher wurde keine äußere Klammer oder Collar-Lösung übernommen.

Geometrieänderungen:

- `VERSION = "1.1.6"`
- `size_y` 93 → 95 mm
- Flansch-Footprint jetzt `65 × 115 × 2.2 mm`
- Hex-Pattern durch `hex_margin_x` 4.0 → 2.8 mm auf 36 Löcher pro Fläche
  erweitert
- passive `-X`-Deckel-Eckfreistiche entfernt, weil sie auf den Druckteilen
  eine sichtbare Diagonalkante erzeugten
- drei interne Anti-Bauch-Bars bei `Y = -36, 0, +36 mm`
- Bars: `2.2 mm` breit in Y, `1.4 mm` hoch in Z, quer über die Kavität
- Bar-Lage `Z = 32.1 … 33.5 mm`; zur Deckelunterseite bei `Z = 37.5 mm`
  bleiben `4.0 mm` Nominalspalt für das obere 3-mm-Filtervlies

Neue Analyse:

- neuer Solver `fem/trough_bulge_fem.py`
- vereinfachtes lineares PA12-Solidmodell des Trogs
- gleichförmiger seitlicher Granulatdruck auf die langen X-Innenwände
- Vergleich Plain-Trog gegen aktuellen Trog mit internen Bars
- optionale Ausgaben: JSON, ParaView-`vtu`, PNG/SVG-Heatmaps

Validierung:

- `./run --with-heal cad`: STEP/STL neu erzeugt, Viewer aktualisiert
- CAD-Ausgabe: Körper `65 × 95 × 40 mm`, Flansch `65 × 115 × 2.2 mm`,
  36 Hex-Löcher pro Fläche, Trogvolumen `34.89 cm³`, Deckelvolumen
  `6.76 cm³`
- STEP→Gmsh→pymeshfix: `trough.stl` wasserdicht und winding-consistent,
  Selbstdurchdringungen `13 → 0`, Volumen praktisch unverändert
- `lid.stl`: wasserdicht und winding-consistent, bereits clean
- `./run fem-bulge --pressure-kpa 5 --variant both --support open`:
  Plain-Trog `0.083 mm` max. Ausbuchtung, aktueller Trog `0.023 mm`;
  Druck für `1.0 mm` Ausbuchtung `60.5 → 217.8 kPa`
- `./run fem-assembly`: Hook-first-Pfad weiterhin plausibel,
  beste Lage `-10°`, `dx = +0.40 mm`, `dz = +1.20 mm`,
  harte Restpenetration 0 Punkte, Schnapper-Interferenz `~0.94 mm`
- `./run fem-snap`: nominale Gesamt-Hebekraft `~10.39 N`
- `./run fem-hook`: passive Hakenleiste bleibt strukturell deutlich über
  dem erwarteten Nutzlastbereich (`~174 … 213 N` im PA12-`1/3`-Proxy)

Entscheidung:

- Keine externen Stützfeatures, weil der Schacht-Fit bereits eng ist.
- Keine kleinen vertikalen Wandrippen als Hauptlösung: die erste FEM zeigte,
  dass die freie obere Kante der dominierende Verformungsmodus ist.
- Interne Querbars sind der aktuelle Kompromiss: sie bleiben innerhalb des
  Außenmaßes, reduzieren die berechnete Ausbuchtung deutlich und lassen
  bewusst Platz für das obere Filtervlies.

## 2026-05-06

### Trogseitige Haken-Retentionslippe ergänzt, Release v1.1.5

Der v1.1.4-Haken selbst war deutlich kräftiger, im X-Z-Schnitt war aber
sichtbar, dass die Trogseite noch eher wie eine offene Seitennut als wie eine
bewusste Gegenraste wirkte. Die Tasche wurde deshalb zweistufig gemacht:

- `VERSION = "1.1.5"`
- untere Retentionstasche: 1.35 mm tief
- oberer Einführkanal: nur 0.55 mm tief
- verbleibende trogseitige Materiallippe: 0.80 mm tief
- reale Hakenüberdeckung bleibt 1.05 mm
- äußere Taschenluft bleibt 0.30 mm
- äußerste Haken-Nase mit 0.2-mm-Fase entschärft

Damit greift die Haken-Nase nicht mehr in eine fast vollständig offene
Vertikalnut, sondern sichtbar unter eine Retentionslippe. Die obere flachere
Tasche bleibt als Einführhilfe für die Hook-first-Montage erhalten.

Validierung:

- `./run --with-heal cad`: STEP/STL neu erzeugt, Viewer aktualisiert
- `./run fem-hook`: lokale Steifigkeit ~1027 N/mm;
  PA12-`1/3`-Proxy-Haltekraft ~174 … 213 N
- `./run fem-snap`: unverändert zu v1.1.4/v1.1.3, nominal ~10.4 N
  Öffnungskraft
- `./run fem-assembly`: Hook-first-Pfad weiterhin plausibel;
  beste Lage `-10°`, `dx = +0.40 mm`, `dz = +0.90 mm`,
  harte Restpenetration 0 Punkte, Schnapper-Interferenz ~0.93 mm
- STL-Diagnose: beide finalen STLs wasserdicht, 0 Randloops,
  0 Selbstdurchdringungen

### Passive Hakenleiste verstärkt und Haltekraft geprüft, Release v1.1.4

Die v1.1.3-Hakenleiste wurde nach haptischer Rückmeldung nochmals separat
geprüft. Wichtiges Ergebnis: `hook_rail_capture = 1.1 mm` war nicht die reale
Überdeckung hinter der Trog-Innenwand. Wegen Deckelspiel/Rabbet-Geometrie lag
der tatsächliche Untergriff nur bei etwa `0.70 mm`. Zusätzlich war der obere
Steg der Hakenleiste durch `hook_rail_depth - hook_rail_capture` nur `0.40 mm`
stark und damit für MJF unnötig filigran.

Geometrieänderung:

- `VERSION = "1.1.4"`
- `hook_nose_outboard = 0.35 mm`
- `hook_rail_depth` 1.5 → 2.1 mm
- realer Untergriff hinter der Trog-Innenwand: 0.70 → 1.05 mm
- äußere Taschenluft bleibt bei 0.30 mm
- oberer Hakensteg: 0.40 → 1.00 mm, Querschnitt 34 mm²

Neuer Hook-Solver `fem/hook_hold_fem.py`:

- lokales lineares PA12-FEM der mittigen Hakenleiste
- oberer Steg am Deckelanschluss geklemmt
- 1 N nach unten auf den unteren Haken-Nasenbereich
- Ergebnis `v1.1.4`: lokale Steifigkeit ~810 N/mm
- PA12-`1/3`-Proxy-Haltekraft strukturell ~103 … 125 N
- Yield-Strain-Skalierung ~308 … 376 N

Interpretation: Für die passive Hakenleiste ist nicht die PA12-Festigkeit der
limitierende Punkt, sondern die Geometrie des Untergriffs. v1.1.4 macht den
Untergriff klarer und den Haken selbst druckbarer, ohne die Tasche tiefer zu
schneiden.

Validierung nach Neuaufbau:

- `./run --with-heal cad`: STEP/STL neu erzeugt, beide STLs geheilt
- `./run fem-hook`: bestanden, Haltekraft-/Geometriecheck wie oben
- `./run fem-snap`: unverändert zu v1.1.3, nominal ~10.4 N Öffnungskraft
- `./run fem-assembly`: Hook-first-Pfad weiterhin plausibel;
  beste Lage `-10°`, `dx = +0.40 mm`, `dz = +1.20 mm`,
  harte Restpenetration 0 Punkte, Schnapper-Interferenz ~0.93 mm

### Aktive Schnapper moderat straffer gemacht, Release v1.1.3

Nach Rückmeldung vom Druckmuster sollte der aktive Schnappverschluss spürbar,
aber nicht drastisch, straffer werden. Die passive Haken-Seite und die
65-mm-Breite bleiben unverändert; geändert wurde nur der aktive
Lippenüberstand:

- `VERSION = "1.1.3"`
- `hook_protr` 1.0 → 1.1 mm
- Öffnungs-Auslenkung `hook_protr + fit_clear`: 1.30 → 1.40 mm

Validierung nach Neuaufbau mit `./run --with-heal cad`:

- Körper bleibt `65 × 93 × 40 mm`, Flansch `65 × 113 × 2.2 mm`
- schnelle Balkenabschätzung: `~4.25 N` lateral pro Schnapper,
  `~4.30 N` Gesamt-Hebekraft
- STEP→Gmsh→pymeshfix bleibt für beide STLs wasserdicht; Diagnostics melden
  0 Randloops und 0 Selbstdurchdringungen

Lokale FEM `./run fem-snap`:

- laterale Federsteifigkeit pro Schnapper: `~7.34 N/mm`
- laterale Auslenkkraft für `1.40 mm`: `~10.28 N` pro Schnapper
- abgeleitete Gesamt-Hebekraft: `~7.98 … 10.64 N`, nominal `~10.39 N`
- maximale Hauptdehnung: `~3.43 %`

Baugruppen-Checker `./run fem-assembly`:

- beste gefundene Hook-first-Lage bleibt `-10°`, `dx = +0.40 mm`,
  `dz = +0.90 mm`
- eingehakte Lage kollisionsfrei (`max penetration = -0.088 mm`)
- Schliessbahn ohne harte Kollision; harte Restpenetration 0 Punkte
- beabsichtigte Schnapper-Einfederung im Kontaktmodell: `snap ~0.94 mm`

Schlussfolgerung: Die v1.1.3-Änderung hebt den FEM-Hebewiderstand von etwa
8.8 N auf etwa 10.4 N an. Das sollte taktil merklich straffer sein, bleibt
aber noch im PA12-`1/3`-Proxyband mit bewusst kleiner Reserve.

## 2026-04-19

### Vollbaugruppen-Kontakt für Deckel gegen Trog

Zur lokalen Schnapper-FEM kam ein separater Baugruppen-Checker hinzu. Der
erste Lauf zeigte noch eine Restkollision an der passiven `-X/-Y`-Deckelecke.
Daraufhin wurden an den beiden passiven Deckelecken kleine Freistiche in
der Draufsicht ergänzt; der Checker wurde danach erneut ausgeführt.

Aktueller Stand:

- neuer Solver `fem/lid_trough_assembly.py`
- voller Deckel gegen vollen Trog
- starre Kinematik, aber mit echter STL-Geometrie beider Teile
- Signed-Distance gegen das Trogmaterial entlang einer Hook-first-
  Bewegungsfamilie um die passive Hakenlinie
- ergänzende Montagezeichnungen über `fem/assembly_sequence_svg.py`

Ergebnis für `v1.1.0`:

- beste gefundene Kipplage im Suchraum: `-15°`, `dx = +0.40 mm`,
  `dz = +1.20 mm`
- eingehakte Kipplage kollisionsfrei
- vertikale Einfädelbahn in dieser Kipplage kollisionsfrei
- Schließbahn in die Endlage ohne harte Restkollision; nur die aktiven
  Schnapper interferieren noch wie vorgesehen elastisch mit `~0.98 mm`
- die passive Seite ist durch die Eckfreistiche jetzt keine Störkante mehr

Schlussfolgerung:

- Die aktuelle mittige Hakenleiste funktioniert jetzt auch als nutzbare
  Hook-first-Kippachse für die Baugruppe.
- Die passive Seite braucht keine weitere Grundsatz-Änderung mehr; die
  lokale Entlastung an den beiden `-X`-Ecken reicht im geprüften Suchraum.
- Offene Restfrage ist nicht mehr die Kinematik, sondern nur noch die
  physische Plausibilisierung am Druckmuster.

### Dokumentation auf 1.1.0-Stand synchronisiert

README, TODO und die Hilfsscripte wurden auf denselben Stand wie Geometrie und
Analysen gezogen:

- README führt jetzt den aktuellen Hook-first-Befund mit passiven
  Eckfreistichen als gültigen Stand und behandelt den früheren negativen
  Checker-Lauf nur noch als überholten Zwischenstand.
- Die erzeugten SVG-Montagezeichnungen und ihre Dateinamen sind dokumentiert.
- Beispielaufrufe für `fem/snap_fit_fem.py` und
  `fem/lid_trough_assembly.py` stellen klar, dass die JSON-/VTK-Zielpfade bei
  Bedarf automatisch angelegt werden.
- TODO verweist bei der Montageprüfung nur noch auf physische
  Druckmuster-Validierung, nicht mehr auf eine prinzipiell blockierte
  Kippkinematik.

### Lokale FE-Baseline für den aktiven Schnapper

Zusätzlich zur bisherigen Balkenabschätzung wurde eine reproduzierbare
3D-FE-Analyse für den aktiven Schnapper angelegt:

- neuer Solver in `fem/snap_fit_fem.py`
- Gmsh für das lokale Tetra-Netz
- scikit-fem für lineare Elastizität
- Lastangriff direkt auf der realen Rastfläche statt am freien Armende

Erste Ergebnisse mit `mesh_size = 0.25 mm` und nominal `E = 2150 MPa`:

- laterale Federsteifigkeit pro Schnapper: `~7.3 N/mm`
- laterale Auslenkkraft für `1.30 mm`: `~9.5 N` pro Schnapper
- abgeleitete Gesamt-Hebekraft: `~6.7 … 9.0 N`
- maximale Hauptdehnung: `~3.2 %`

Wichtigste Erkenntnis:

- Die FE liegt merklich über der einfachen Cantilever-Formel, weil die
  Last realistisch auf der kurzen Haltefläche bei `z ≈ -8.5 mm` und nicht
  am absoluten Armende ansetzt.
- Die Geometrie bleibt damit für werkzeugloses Öffnen weiterhin plausibel.
- Die Dehnungsreserve ist kleiner als die reine Balkenformel vermuten liess,
  bleibt aber noch im HP-`1/3`-Proxyband für PA12.

### Deckel-Redesign auf einfache Hakenleiste + selbstlösende Schnapper, Release v1.1.0

Ausgangspunkt war die Sorge, dass zwei symmetrische Rastnasen zwar halten,
aber beim Öffnen unnötig fummelig sind. Gleichzeitig waren die beiden Extreme
unbefriedigend:

- reine Führungsleiste: zu wenig passive Haltefunktion
- tiefes Haken-/Taschensystem: unnötig komplex für MJF und diese Anwendung

Das Design wurde deshalb auf einen Mittelweg umgestellt:

- **1 passive Hakenleiste** auf der -X-Seite des Deckels
- **1 flache Haken-Tasche** in der -X-Trogwand
- **2 Cantilever-Schnapper** auf der +X-Seite
- **1 kleine Zuglippe** am Deckel auf der Schnapper-Seite
- **1 Freistellung** in der Trogwand, damit die Lippe mit einem Finger
  erreichbar ist

**Warum diese Aufteilung**:

- Klare passive Halte-Seite statt bloßer Führung
- Einfacher als ein tiefes verdecktes Hakensystem
- Montage wird geführt: Haken erst in die Tasche einsetzen, dann
  Schnapper-Seite herunterdrücken
- Öffnen wird kontrolliert: an der Lippe anheben, die Schnapper cammen über
  ihre obere Rampe selbsttätig frei, Deckel klappt an der Haken-Seite hoch
- Toleranzfreundlicher als 4 aktive Schnapper, die alle gleichzeitig sauber
  einrasten müssten

### Kraftabschätzung für das Öffnen

Die Schnapper wurden mit dem klassischen Cantilever-Modell abgeschätzt
(`F = 3 E I δ / L³`, `I = b t³ / 12`) für MJF-PA11 mit
`E ≈ 1.6 … 1.8 GPa`.

Vergleich:

| Geometrie | Auslenkung `δ` | Armlänge `L` | laterale Kraft pro Schnapper | Dehnung |
|---|---|---|---|---|
| bisher `v1.0.2` | 0.80 mm | 6.0 mm | ~8.9 … 10.0 N | ~3.33 % |
| Zwischenstand `v1.1.0` | 0.80 mm | 7.0 mm | ~5.6 … 6.3 N | ~2.45 % |

Zusätzlich wurde die Geometrie der Rastlippe geändert:

- kurze **Haltelänge** `0.4 mm`
- obere **Auslöserampe** `1.4 mm`
- mittige **Zuglippe** `1.2 mm` tief

Mit einer groben Reibannahme `μ ≈ 0.2` ergibt das für die neue
Hebebewegung eine geschätzte Gesamt-Fingerkraft von **~4.5 N** für beide
Schnapper zusammen. Die laterale Federkraft bleibt höher, aber sie muss nicht
mehr direkt mit zwei Fingern an den Armen eingeleitet werden.

Die passive Haken-Seite hat bei der gewählten Geometrie etwa
`hook_rail_foot_depth - hook_rail_leg_depth ≈ 0.5 mm` wirksame Überdeckung.
Damit ist die Gegenseite nicht nur "geführt", sondern nimmt beim Öffnen den
Gegenmomentpfad formschlüssig auf, ohne geometrisch auszuufern.

**Schlussfolgerung**:

- Werkzeugloses Öffnen ist mit `v1.1.0` jetzt auch **einhändig** realistisch
- zerstörungsfreier Betrieb ist bei den erwarteten wenigen Zyklen klar
  plausibel
- die Reserve zur groben PA11-Streckgrenze (~5 %) ist jetzt deutlich besser

Die Schnapperlänge wurde deshalb bewusst von `6.0` auf `7.0 mm` erhöht;
`hook_arm = 1.0 mm` bleibt unverändert, damit das Feature MJF-konservativ
bleibt. Die passive Gegenseite wurde als **einfache** Haken-/Taschen-Paarung
ausgeführt, weil das der beste Kompromiss ist: mehr Klarheit und Haltefunktion
als eine Führungsleiste, aber deutlich weniger Komplexität als ein tiefes
verdecktes Hakensystem. Die Öffnungsbewegung ist damit kinematisch eindeutig:

1. Finger zieht an der +X-Zuglippe
2. +X-Schnapper cammen frei
3. -X-Haken bleibt eingehakt und bildet die Drehachse
4. Deckel klappt auf
5. Zum vollständigen Abnehmen wird der geöffnete Deckel leicht zur
   Schnapper-Seite verschoben und dann nach oben entnommen

### `_heal_stl()` toleriert fehlendes `pymeshfix`

Die bisherige Toolchain brach lokal ab, wenn `pymeshfix` nicht installiert
war. Das war unnötig streng, weil STEP/STL zu diesem Zeitpunkt bereits
exportiert waren. `_heal_stl()` behandelt `pymeshfix` jetzt als **optionale**
Dependency:

- mit `pymeshfix`: unverändertes Heal-Verhalten
- ohne `pymeshfix`: Hinweis auf STDOUT, Export läuft trotzdem vollständig durch

## 2026-04-17

### MJF-Optimierung und FreeCAD-Abkehr

Entfernen der FreeCAD-Toolchain; weiter nur build123d + ocp-vscode als
Designer/Viewer-Kombination.

**Begründung**: Der Editier-Workflow in FreeCAD (Spreadsheet-Expressions +
Sketch-Klicks) war für dieses Projekt nie nötig; alle Parameter-Iterationen
liefen ohnehin über Script-Edits. Durch build123d entfallen topologische
Naming-Probleme und fragile MapMode-Heuristiken.

### MJF-Optimierungen am Design

Mehrere parametrische Änderungen am `carbon_filter_build123d.py`:

| Parameter | Vorher | Nachher | Grund |
|---|---|---|---|
| `wall` | 1.8 mm | 2.2 mm | Nach Rabbet-Schulter blieb nur 0.3 mm Wand — nicht druckbar |
| `floor` | 1.8 mm | 2.2 mm | Symmetrie zu `wall` |
| `fit_clear` | 0.15 mm | 0.30 mm | MJF-Standard (±0.3 mm Maßtoleranz) |
| `hex_margin_*` | 3.0 mm | 4.0 mm | Mehr Rahmenmaterial um Hex-Perforation |
| `outer_fillet` | 1.5 mm | 2.0 mm | Haptik und Oberfläche |
| `hook_root_fil` | — | 0.5 mm | Neu: Kerbspannungsreduktion am Armansatz |

**Rabbet-Geometrie**: Die bisherige Version cuttete den OUTER-Ring des
Wandabschlusses, was eine stehende 0.3 mm-Innenlippe hinterliess. Neue
Logik: das Rabbet WEITET die Kavität am oberen Ende (Rechteck grösser als
Kavitäts-Rechteck, cut `rabbet_depth` tief). Ergibt eine saubere Schulter
von `shelf_w` Breite, auf der der Deckel aufsitzt.

**Snap-Mechanik**: Grundsätzlich umgestellt auf den Ansatz „Durchbrüche in
Aussenwand + Lippen schnappen durch". Verworfene Alternativen:

- _Interner Catch an Cavity-Wand-Nut_: benötigt Horizontal-Nut, klassisches
  Powder-Trap-Problem beim MJF-Entpulvern
- _Lippe catcht auf Schulter_: bei gegebenen Wandstärken geometrisch nicht
  sauber darstellbar ohne Arm-Kollision mit Cavity-Wand
- _Friktionspassung ohne Hooks_: wäre am einfachsten, aber User hatte
  explizit Rastnasen spezifiziert

Die Durchbrüche-Variante ist MJF-ideal: keine geschlossenen Untermasse,
klares akustisches Feedback, Deckel reversibel öffenbar (alle vier Lippen
gleichzeitig eindrücken).

### Material PA11

Umstieg von PA12 auf PA11. Begründung im README dokumentiert (höhere
Bruchdehnung, bessere Dauerfestigkeit, niedrigere Feuchteaufnahme). Bei
dem Duty-Cycle (~10 Zyklen in 5 Jahren) kein technischer Zwang, aber
komfortabler Sicherheitsabstand.

### Repo-Struktur

CLAUDE.md, TODO.md, LOGBOOK.md angelegt für strukturierte Fortführung des
Projekts.

## 2026-04-18

### Schacht-Fit-Redesign

Geometrie an den tatsächlichen Lüftungsschacht angepasst. Schachtmaße (aus
Foto und Benutzerangaben verifiziert):

- Harte Innenbreite 70 mm, je ca. 5 mm Schaumstoff links/rechts
- Höhe 100 mm, harte Ober- und Unterwand
- Tiefe 100 mm
- Luftrichtung: hinten → vorne (durch 3 aktive Wohnungsabsaugungen
  gezogen, 3 Fenster × 2 Schächte = 6 parallele Pfade)

**Änderungen am Design**:

| Parameter | Vorher | Nachher | Grund |
|---|---|---|---|
| `size_x` | 65 | 62 | 1.5 mm Schaumstoff-Kompression pro Seite: dichtet und rutscht noch rein |
| `size_y` | 45 | 40 | Optimum aus Ergun-ΔP und AC-Kapazität bei aktiven Absaugungen |
| Snap-Durchbrüche | 4 (alle Seiten) | 2 (nur X) | Y-Flächen = Hex-Luftweg, Z-Flächen = an den harten Schachtwänden |
| Rastnasen am Deckel | 4 | 2 | Entsprechend |
| Fingermulde vorn | — | 25 × 6 × 1.2 mm | Herausziehen aus dem Schacht |

**Begründung Tiefe 40 mm**: Bei Kassettenquerschnitt ~48 cm² und 6
parallelen Pfaden pendelt sich die Strömung durch AC-Bett bei
Bad-/Küchenabsaugung (40–100 Pa statisch) auf ~0.5 m/s Face Velocity
ein. Ergun-ΔP bei 30 mm Bett (nach Wänden und Filtervlies) ≈ 75 Pa —
verträglich. Kohle-Masse ~78 g/Kassette → ~6 Monate Standzeit in
normaler Wohnluft. Verworfene Alternativen:

- 45 mm (Status quo): ~110 Pa ΔP, fängt an Absaugung zu drosseln
- 30 mm: ΔP ok, aber Standzeit unter 4 Monaten zu kurz für Komfort
- 55 mm: >150 Pa ΔP, nur bei überdimensionierten Absaugungen sinnvoll

**Begründung 2 statt 4 Rastnasen**: Einrastung auf Y-Flächen würde die
Hex-Perforation unterbrechen (Strömung und Optik), Einrastung auf
Z-Flächen würde an den harten Schachtwänden anschlagen und das Einsetzen
verhindern. Nur die X-Seiten stehen im Schaumstoff und erlauben
Durchbrüche ohne Schachtkonflikt. Zwei Rastnasen reichen für die
Haltekraft (Deckel ist statisch, nur Eigenmasse + Filtervlies-Druck).

**Fingermulde**: Der Schacht ist tief (100 mm) und die Kassettenoberkante
fluchtet bündig mit der Schachtkante. Ohne Griffmulde ist die Kassette
kaum herausnehmbar. 1.2 mm Tiefe bei 2.2 mm Wand → 1.0 mm Restwand
(>= MJF-Minimum).

### Grundlegende Umkonstruktion: vertikaler Luftstrom durch den Filter

Bei der Einbaubesprechung wurde klar, dass die bisherige Konstruktion
(horizontaler Luftstrom durch Hex-Gitter in den Y-Flächen, Deckel an der
Seite) den eigentlichen Zweck verfehlt: **die Luft muss durch das
Kohlebett, nicht daran vorbei**. Neue Konstruktion:

- Hex-Gitter auf **Boden und Deckel** (Z-Flächen)
- Z wird zur Luftstromachse — beim Einbau wird die Kassette um 90° gekippt,
  sodass Z horizontal zur Schachttiefe wird
- Neue Nennmasse: `size_z = 40 mm` (Luftweg), `size_y = 93 mm`
  (Schachthöhe), `size_x = 62 mm` (unverändert)
- Deckel schnappt von **oben** auf (Befüllung: Deckel ab → Vlies → Kohle →
  Vlies → Deckel drauf)

**Einbaulage umgedreht**: Deckel zeigt nach hinten (Aussenluft-Seite),
Boden mit Fingermulde nach vorne in die Wohnung. Gründe:

- Beim Ziehen an der Fingermulde kommt die gesamte Kassette mit, nie nur
  der Deckel. Umgekehrt würde der Zug ausser der Reibung auch direkt die
  Rastnasen belasten und die Kassette in sich auseinanderziehen können.
- Der Luftstrom (hinten → vorne) drückt den Deckel in den Rabbet-Sitz,
  nicht heraus.

**Einschub-Stopper als Bodenflansch**: Ein umlaufender Flansch am Boden
(Z = 0 … 2.2 mm) ist breiter als die harte Schachtöffnung und fängt an
der Schacht-Frontkante. Erste Version hatte den Flansch rundum 5 mm
vergrössert (72 × 103 mm) — das überschreitet jedoch die 70 mm
X-Hartöffnung und blockiert den Einschub. Korrigiert: Flansch nur in Y
verbreitert (62 × 103 × 2.2 mm), X bleibt auf Körperbreite. Die 3 mm
Y-Überstand oben und unten reichen zum Einfangen; in X geht der Flansch
sauber durch die 70-mm-Öffnung. Die Kassette steht 2.2 mm aus der
Schachtkante (User-Limit 5 mm).

**Moosgummi-Axialdichtung**: Y-Flächen der Kassette kontaktieren die
harten Schachtwände oben/unten. Dort werden Moosgummistreifen aufgeklebt
(user-applied, nicht gedruckt), um axiale Leckluft am Filterbett vorbei
zu verhindern. Die Y-Flächen werden deshalb glatt und durchbruchfrei
konstruiert — keine Hex, keine Snap-Schlitze.

**Armwurzel-Fillet — robuste Kantenauswahl**: Der vorherige
Kantenselektor (`filter_by_position` auf Z-Höhe) griff auch die
Lid-Perimeterkanten und warf damit gelegentlich ValueError. Neu: pro
Arm eine XY-Bounding-Box, und nur Kanten deren Mittelpunkt innerhalb
liegt werden gefilletet. Tolerant mit 0.05 mm Saum, Fallback-Meldung
falls gar keine Kanten matchen.

**Verworfene Alternativen**:

- _Hex in Y-Flächen, Deckel seitlich_: ursprünglicher Ansatz, gibt
  horizontalen Bypass-Strom statt Durchströmung
- _Deckel vorne (Apartment-Seite)_: Fingermulde würde Deckel lösen, nicht
  Kassette ziehen; Luftstrom würde Deckel herausdrücken
- _Flansch rundum 5 mm_: X-Überstand blockiert Einschub in 70-mm-Öffnung
- _Axiale Dichtung per Geometrie (Dichtlippen, Schürzen)_: MJF drucken
  diese Feinstrukturen unzuverlässig; Moosgummi ist zuverlässiger und
  tauschbar

### Fingermulde entfernt, Snap-Slot-Fix, Hex-Raster vergrössert

Nach erstem Viewer-Check (User-Feedback):

**Snap-Slot-Bug -X-Seite**: Die zweite Slot-Cut-Ebene hatte Offset
`-size_x/2 + 1.0` (bei x=-30, also _innerhalb_ der Aussenwand); richtig
ist `-size_x/2 - 1.0` (bei x=-32, _ausserhalb_ der Wand). Damit ging der
Cut nur durch die inneren ~1.2 mm der -X-Wand statt sauber durch, und die
Deckel-Rastnase hatte keinen Durchbruch zum Einrasten. Fix: Vorzeichen
korrigiert → beide Slots schneiden jetzt symmetrisch durch.

**Fingermulde (40 × 8 × 1.2 mm) entfernt**: Auf Niveau der Bodenaussenseite
war sie ergonomisch sinnlos — eine flache Vertiefung ohne Unterkante zum
Hinterhaken. Die 5 mm Y-Flansch-Überstände (oben und unten an der
Apartment-Seite) bieten den natürlichen Fingergriff: Daumen oben,
Zeigefinger unten, direkter Auszug. Keine extra Geometrie nötig, Boden
bleibt strukturell geschlossener.

**Hex-Raster 8 → 10 mm flats**: Offenfläche steigt von 44 % auf 48 % der
Kavitätsfläche. Der Gewinn ist moderat, weil die 4 mm Margin (MJF-Verzug)
den Rand dominiert — dennoch besser für freies Pulverrieseln und optisch
aufgeräumter. Screen-ΔP bei 0.5 m/s Face Velocity unter 1 Pa in beiden
Varianten, also nicht strömungslimitierend (Bett dominiert mit 50–80 Pa).
Stegbreite bleibt 1.2 mm — gut über MJF-Minimum 1.0 mm, konservativ.

**Flanschüberstand 5 → 10 mm**: Der bisherige 5-mm-Überstand reichte als
Stopper, bot aber wenig Fingerauflage (die Fingerkuppe braucht ~8 mm
Greiftiefe für sicheren Zug gegen den Unterdruck der Absaugung). Mit je
10 mm gibt es einen komfortablen Griffrand. Gesamt-Flansch jetzt
62 × 113 × 2.2 mm. Kollidiert nicht mit der Fensterrahmen-Umgebung.

### Repo-Init, v1.0.0-Tag, Output-Neuordnung

Repo mit `git init` auf `main` initialisiert. Alle Dateien (Script,
Dokumentation, STEP/STL-Exporte) in einen Root-Commit `c24868b` gelegt und
als `v1.0.0` getaggt. STEP-Artefakte liegen unter `output/STEP/`, STL unter
`output/STL/` (script-relative Pfade über `Path(__file__).resolve().parent`,
sodass Läufe aus beliebigem CWD in denselben Ordner exportieren).

**Begründung Unterordner**: Die Unterscheidung STEP (maschinenlesbarer CAD-
Austausch, z. B. mit Bureau) vs. STL (direkter Druckfluss) soll in der
Ordnerstruktur sichtbar sein, damit beim Versand klar ist, welche Datei für
welchen Zweck dient. Beim Tagging von v1.0.0 wurde die Ordnerneuordnung
destruktiv in den Root-Commit eingefaltet (statt neuer Commit), da das Tag
noch nicht publiziert war und der lineare Commit-Graph sauber bleiben sollte.

### DFM-Optimierung (Design for Manufacturability)

Systematischer Durchgang durch alle 90°-Kanten und -Übergänge am Körper und
Deckel, mit explizit gewählten Radien pro Feature. Ziel war es, die
Druckbarkeit und Langlebigkeit zu verbessern, ohne die funktional relevanten
Masse (Flansch-Stopper, Dichtflächen, Snap-Geometrie) zu verändern.

**Angewandte Rundungen und Fasen** (alle in `carbon_filter_build123d.py`
parametrisiert; Werte in Klammern):

| Feature | Op | Wert | Zweck |
|---|---|---|---|
| Körper-Senkrechtkanten | Fillet | 2.0 mm | bereits vorhanden |
| Flansch-Unterseite (4 Aussenkanten Z=0) | Chamfer | 0.8 mm | Handling, Griffgefühl, kein Absplittern |
| Flansch-Y-Step (2 gerade Kanten Z=floor) | Fillet | 1.0 mm | Kerbspannung Innenecke |
| Flansch-Eckenschelfs (4 Bögen Z=floor) | Chamfer-Fallback 0.5 | — | OCCT-Konflikt, akzeptiert |
| Kavitäts-Bodeninnenkanten (4 Kanten Z=floor) | Fillet | 1.0 mm | Kerbspannung + Entpulvern |
| Rabbet-Schulterkanten (Z=size_z−rabbet_depth) | Fillet | 0.3 mm | abrupten Step weichen |
| Snap-Armwurzel | Fillet | 0.5 mm | bereits vorhanden, beibehalten |

**Hook-Lip von 0.45 auf 0.50 mm angehoben**: `hook_protr` lag unter dem
MJF-Minimum für positive Features (0.5 mm) und wäre potenziell mit
abgerundeter Lippen-Spitze gedruckt worden → unsauberes Einrasten. Auf 0.50
mm angehoben: maximale Cantilever-Dehnung steigt von 3.12 % auf 3.33 %
(PA11-Fliessdehnung ~5 %), weiterhin komfortabel elastisch.

**Per-Kanten-Fallback für OCCT-Konflikte**: `fillet()` und `chamfer()` in
build123d/OCCT werfen eine Exception für den gesamten Batch, wenn **eine
einzige** der übergebenen Kanten den Radius nicht akzeptiert. Lösung: zwei
Hilfsfunktionen `try_fillet()` / `try_chamfer()`, die zuerst den Batch
versuchen und bei Fehler auf per-Kanten-Versuch fallen. Fehlschläge werden
mit Kanten-Label und Radius auf STDOUT protokolliert. Das rettet alle
Kanten, die OCCT problemlos verarbeiten kann, auch wenn einzelne Kanten
scheitern.

**Bekannte Limitation (akzeptiert): 4 Flansch-Eckenschelfs**: An den 4
Körperecken entsteht beim Union von Körper (mit 2 mm vertikalem
Eckenfillet) und Flansch (rechteckig, ohne eigenes Fillet) ein kleines
"Shelf" — eine bogenförmige Kante bei Z=floor zwischen der zylindrischen
Körperecken-Oberfläche und der ebenen Flansch-Oberseite. OCCT verweigert
hier sowohl Fillet als auch Chamfer bei jedem Radius (getestet:
0.3/0.5/1.0 mm), weil die Tangente zur angrenzenden Zylinderfläche nicht
konsistent aufgelöst werden kann. Die Stellen sind ~2×2 mm, kosmetisch,
nicht lasttragend, nicht Dichtfläche. MJF druckt sie sauber; das Shelf
bleibt als akzeptierter Kompromiss bestehen. Ein Redesign (z. B. Flansch
mit eigenen Ecken-Fillets ausstatten, damit Union-Topologie kompatibel
wird) wäre möglich, aber mit Risiko weiterer Topologie-Probleme und
geringem funktionalem Gewinn.

**Topologische Ordnung der Operationen**: Getestet wurden verschiedene
Reihenfolgen (Straights-first vs. Arcs-first für den Flansch-Y-Step).
Ergebnis: **Straights zuerst** (2/2 Kanten filetieren bei 1.0 mm
erfolgreich), Arcs danach (4/4 werden vom Fallback übersprungen). Umgekehrt
gelingen 2/4 Arcs, aber dann scheitern die Straights komplett — weil
die erfolgreiche Arc-Fillet-Operation die Nachbar-Topologie verändert.
Straights-first maximiert den sichtbaren Verbesserungsgewinn auf den
langen Y-Kanten, wo die Kerbspannungsreduktion am meisten bringt.

**Verworfene Alternativen**:

- _Alle konkaven Kanten mit einheitlichem 0.5-mm-Fillet_: zu klein für
  Flansch-Y-Step (1.0 mm ist spannungsoptimal), zu gross für Rabbet
  (eigentlich reichen 0.3 mm, grössere Fillets fressen Schulterbreite)
- _Chamfer statt Fillet für Flansch-Step_: funktioniert, aber konkave
  Innenkanten profitieren stärker von Rundung als Fase (stetige Tangente
  statt erneutem Kantenknick)
- _Rabbet komplett weglassen_: nein, der Rabbet sitzt die Deckeloberkante
  bündig und ist funktional unverzichtbar; der 0.3-mm-Fillet soll nur die
  Kanten weicher machen
- _Redesign für Flansch-Ecken-Kompatibilität_: wurde für v1.0.1
  zurückgestellt; das Shelf hat keinen bekannten Nachteil

### Versionsgravur auf dem Flansch (v1.0.1)

Neue `VERSION`-Konstante im Script-Header, als 0.6 mm tiefe Vertiefung
(Font-Size 5 mm, Arial) auf die Apartment-seitige Fläche des
+Y-Flansch­überstands graviert. Platziert bei Z = 0 … 0.6 mm, vertikal
mittig im 10-mm-Überstand.

**Spiegelungs-Fix**: Der erste Wurf nutzte `Plane.XY` als Sketch-Ebene —
der Text war in der +Z-Blickrichtung lesbar, aber bei der effektiven
Benutzerperspektive (-Z, Apartment-Seite) spiegelverkehrt (Beobachter-Rechts
kippt von +X auf -X beim Wechsel der Blickseite). Fix: Sketch auf einer
Ebene mit Normalen -Z und `x_dir = -X`, damit `y_dir = +Y` (rechtshändig)
bleibt und die Zeichen aus der Apartment-Richtung korrekt orientiert sind.
Extrude-Amount wird negativ gewählt, sodass der Cut wieder in +Z-Richtung
ins Material geht.

**Font-Size 5 mm** (zunächst 4 mm): nach Viewer-Probe auf 5 mm angehoben,
damit die Zeichen auch nach MJF-typischem Randverzug klar lesbar bleiben.
Paßt weiterhin in den 10-mm-Überstand.

**Begründung Platzierung**:

- **+Y-Flanschüberstand**: solid (keine Hex-Perforation, kein Snap-Schlitz),
  in der Sichtlinie des Benutzers (Apartment-Seite), gleichzeitig Griffrand
  → die Gravur ist beim Wechsel immer sicht- und fühlbar
- **Tiefe 0.6 mm**: MJF druckt diese Tiefe crisp. Restboden unter der
  Gravur = 2.2 mm − 0.6 mm = 1.6 mm, deutlich über MJF-Minimum 1.0 mm.
- **Font-Size 5 mm**: passt in den 10 mm Überstand und bleibt auch nach
  MJF-Randverzug klar lesbar (4 mm waren am Rand des Lesbaren).

**Topologie-Überlegung**: Die Gravur erzeugt viele neue Kanten bei Z ≈ 0
(Textkonturen). Deshalb wird die Gravur NACH dem `flange_bot_cham`-Chamfer
ausgeführt — so fasst der Z-Positions-Filter des Chamfers nur die 4
Flansch-Perimeter-Kanten und nicht die Textkonturen (OCCT würde Chamfer auf
Text-Kanten verweigern und den gesamten Batch abbrechen lassen, oder das
Ergebnis würde visuell unsauber).

**Maintenance-Pflicht**: `VERSION` steht zentral im Script-Header. Beim
Bump muss sie synchron im README mitgeführt werden (oberhalb der
Funktionsbeschreibung) und beim Release als git-Tag `vX.Y.Z` gesetzt
werden. Die Drei-Punkt-Regel ist in CLAUDE.md verankert.

**Verworfene Alternativen**:

- _Gravur auf der Deckel-Oberfläche_: wäre zwischen den Hex-Löchern gezwängt
  und beim Einbau verdeckt (Deckel zeigt nach hinten in den Schacht)
- _Erhabener Text statt vertieft_: würde gegen die Dichtflächen der
  Schachtkante drücken und lokal den Flansch-Sitz stören
- _Gravur auf den X-Wänden (Schaumstoffseite)_: unsichtbar nach Einbau
- _Gravur auf den Y-Wänden_: kollidiert mit Moosgummi-Dichtung
- _Gravur mittig auf der Flansch-Bodenfläche_: mittig sind die
  Hex-Perforationen, Text-Kontur würde Hex-Ränder schneiden

### Deckel-DFM: 90°-Kanten gesoftened

Rückfrage des Users („Sind die 90° Kanten des Deckels so ok?") → Analyse
und konsistente Behandlung analog zum Trog:

- **`lid_corner_fil = 1.0 mm`** (4 vertikale Deckel-Senkrechtkanten):
  Handling und visuelle Konsistenz zum Körperecken­fillet. 2.0 mm wie am
  Körper wäre am kleineren Deckel-Footprint zu dominant.
- **`lid_top_cham = 0.5 mm`** (4 Oberkanten bei Z=size_z): Sichtseite von
  oben, Absplitter­schutz, keine scharfe Kante unter dem Finger­druck beim
  Öffnen.
- **`lid_bot_cham = 0.2 mm`** (4 Unterkanten bei Z=size_z−lid_thk):
  Rabbet-Einführschräge. Nur 2/4 Kanten akzeptiert (beide Y-Seiten).
  Die 2 X-Seiten-Kanten verweigert OCCT konsistent auf 0.3/0.2/0.15 mm,
  weil die 0.5-mm-Armwurzelfillet am Tab-Anschluss (X≈28.8) nur 0.7 mm
  vom X-Perimeter (X=29.5) entfernt liegt — Tangentenkonflikt. Die 2
  X-Kanten bleiben scharf; das ist kein Druckproblem, MJF zeichnet sie
  sauber ab und sie zeigen zur Rabbet-Schulter hin, nicht zur Hand.

**Operations-Reihenfolge**: Chamfers **vor** Eckenfillet. Wird der
Eckenfillet zuerst ausgeführt, ändert sich die Perimeter-Topologie (die
4 Eckenkanten sind nun Bögen statt kurze gerade Stücke), und die
nachfolgenden Chamfer-Selektionen lehnt OCCT ab. Die umgekehrte
Reihenfolge (erst Chamfer auf die pristinen 4 Perimeter-Kanten, dann
Fillet auf die 4 Eckenkanten) funktioniert konfliktfrei.

**Klarstellung zur MJF-Druckbarkeit**: Das MJF-Laserscanfeld erzeugt
keine prozessbedingten Schwierigkeiten mit 90°-Kanten. Die Softening-
Operationen dienen hier ausschliesslich Haptik/Handling/Optik, nicht
der Druckbarkeit.

### STL-Mesh-Heal für Bureau-Upload (pymeshfix)

Nach Upload von `trough.stl` beim MJF-Bureau zeigte deren DFM-Analyse
1 nicht-manifold Kante, 71 Abschlusskanten und 117 Selbstdurchdringungen
(jeweils <0.02 % der Gesamt-Primitive, aber Slicer lehnen ab). Ursache:
OCCT's Standard-Tessellation setzt an den Tangentennähten von Fillets
und Chamfers T-Vertices, die je nach Nachbar­face nicht exakt koinzident
sind.

**Lösung**: Post-Processing-Schritt `_heal_stl()` nach dem STL-Export,
implementiert mit `pymeshfix` (Attene-Algorithmus, purpose-built für
topologische Mesh-Reparatur).

**Trough**: heilt robust von 1 Randloop + 296 Selbstdurchdringungen auf
0 / 0, Volumenerhaltung 33.53 → 33.60 cm³ (0.2 % Differenz durch fill_holes).

**Lid**: heilt NICHT. 83 Selbstdurchdringungen sitzen topologisch
fundamental (hex-perforierte Platte mit 28 Durchbrüchen + Snap-Arm-Wurzel­
fillet bei 0.5 mm). `strong_intersection_removal` entfernt die
konfliktierenden Dreiecke und kaskadiert über `fill_holes` in eine inverse
Geometrie-Rekonstruktion — das Endergebnis schrumpft von 7.25 auf 0.04 cm³
(99.4 % Volumen­verlust). Der Volumen-Wächter (≤ 5 % Abnahme) im
`_heal_stl` bricht deshalb ab und behält das Original-STL.

**Tessellations-Scan**: Angular-Tolerance von 0.02 bis 0.3 rad getestet —
Selbstdurchdringungen bleiben (31–204 Stück), saubere Tessellation nicht
erreichbar. Das ist kein Bug im Script, sondern eine OCCT-Limitation
bei hochgenus-Topologien.

**Upload-Strategie** (bestätigt 2026-04-18):
- `trough.stl` (geheilt) für MJF-Bureau — DFM clean.
- `lid.stl` (ungeheilt, 83 Selbstdurchdringungen ~2.5 %) — vom Bureau
  akzeptiert, Auto-Heal kommt damit klar. Kein Handlungsbedarf.
- `lid.step` bleibt als alternative BRep-Quelle verfügbar (clean by
  construction), wird aber für den aktuellen Bureau-Workflow nicht benötigt.

**Verworfene Alternativen**:
- _`pymeshfix.clean_from_file`_: verwirft "kleine Komponenten" per
  Default; für hex-perforierte Platten fatal
- _trimesh-only heal_: erreicht beim Trough nur watertight=False mit
  145 broken faces — trimesh's `fill_holes` schließt keine Loops mit
  T-Vertex-Artefakten zuverlässig
- _Voxelisierung + Marching Cubes_: rundet scharfe Kanten, nicht mit
  0.30-mm-Fit-Toleranz vereinbar
- _manifold3d Self-Union_: Engine nicht in der `ocp`-Env installiert;
  pymeshfix ist leichter

### Release v1.0.2

Sammelrelease der seit v1.0.0 kumulierten Änderungen:

1. **Versionsgravur** (ursprünglich als v1.0.1 geplant) auf dem
   +Y-Flanschüberstand, 5 mm Font, 0.6 mm tief, mit Spiegelungs-Fix über
   Plane(x_dir=-X, z_dir=-Z).
2. **DFM-Optimierung** am Trog (Flansch-Fasen/Fillets, Kavitäts-Boden,
   Rabbet-Schulter, Per-Kanten-Fallback für OCCT-Grenzfälle).
3. **Deckel-DFM**: Eckenfillet 1.0 mm, Oberkanten-Chamfer 0.5 mm,
   Unterkanten-Chamfer 0.2 mm (2/4, X-Seiten OCCT-verweigert).
4. **STL-Mesh-Heal** mit `pymeshfix` nach Bureau-DFM-Feedback. Trough
   heilt auf 0 Randloops / 0 Selbstdurchdringungen; Lid bleibt original
   (Bureau-Auto-Heal akzeptiert die 83 Restdurchdringungen).

Versionssprung von v1.0.0 direkt auf v1.0.2 (die v1.0.1-Gravur-Arbeit
wurde nie getaggt; der Bump geht in einem Commit auf).

## 2026-05-06

### Automatische Pip-/Venv-Umgebung

Der Projektworkflow nutzt jetzt einen lokalen Wrapper `./run`, der eine
`.venv/` im Repo anlegt und die Pip-Abhängigkeiten aus `requirements.txt`
installiert. Die Installation wird über einen Hash-Stempel nur wiederholt,
wenn sich das Manifest ändert. Der Wrapper wählt automatisch eine Python-
Version im Bereich 3.9–3.12, da die CAD/OCP-Native-Wheels nicht zuverlässig
für jede neueste Python-Version bereitstehen.

**Kommandos**:

- `./run setup` erstellt bzw. aktualisiert die Umgebung
- `./run cad` startet das build123d-/ocp-vscode-Script
- `./run fem-snap` startet die lokale Schnapper-FEM
- `./run fem-assembly` startet die Vollbaugruppen-Kontaktprüfung
- `./run drawings` erzeugt die Montage-SVGs
- `./run python ...`, `./run pip ...` und `./run shell` geben direkten
  Zugriff auf dieselbe Umgebung

**Optionale Heal-Abhängigkeit**: `pymeshfix` liegt bewusst in
`requirements-heal.txt` und wird nur mit `./run --with-heal setup`
installiert. Grund: Der normale CAD-/FEM-Workflow soll nicht an möglichen
VTK-/pymeshfix-Installationsproblemen hängen. Ohne `pymeshfix` bleibt der
STL-Export lauffähig; der Heal-Schritt wird wie bisher nur protokolliert
übersprungen.

**Verworfene Alternative**: Automatisches `pip install` direkt in den
CAD-/FEM-Scripts. Das würde Importe mit Netzwerk-/Installer-Seiteneffekten
vermischen und Fehler schwerer lesbar machen. Der Wrapper hält die Umgebung
reproduzierbar, ohne die Modell- und Analyse-Scripts mit Setup-Logik zu
belasten.

### Breite nach Druckmuster-Fit auf 65 mm erhöht, Hook verstärkt und STL-Export remesht, Release v1.1.2

Nach Rückmeldung am gedruckten Muster ist in X-Richtung deutlich mehr Platz
im Schacht als mit `size_x = 62 mm` genutzt wurde. Die Baugruppe wurde daher
auf `size_x = 65 mm` verbreitert; der Bodenflansch bleibt ohne X-Überstand
und folgt der Körperbreite, also jetzt `65 × 113 × 2.2 mm`.

**Geometrie-Folgen**:

- `VERSION = "1.1.2"`; die neue Geometrie ist damit auch in der
  Flanschgravur sichtbar.
- Nutzbarer Bettquerschnitt steigt auf `60.6 × 88.6 mm` (~54 cm²).
- Kohlebettvolumen bei `29.3 mm` Bettiefe: ~157 cm³, also ~71 g
  Aktivkohle bei 450 kg/m³ Schüttdichte.
- Hex-Pattern bleibt bei 28 Löchern pro Seite; durch die grössere Kavität
  sinkt die relative Offenfläche auf ~45 %, absolute Öffnungsfläche bleibt
  ~24 cm².
- Passive Haken-Überdeckung wurde nach Druckmuster-Feedback von `0.6 mm`
  auf `1.1 mm` erhöht. Die Tasche folgt mit `1.35 mm` Tiefe und lässt noch
  ~0.85 mm Restwand in der X-Seitenwand stehen.

**Passive Haken-Tasche**: Der erste Checker-Lauf mit nur verbreitertem X
fand zwar eine kollisionsfreie eingehakte Lage, aber die vereinfachte
vertikale Einfädelbahn hatte eine harte Restpenetration an der passiven
Hakenleiste. Die Tasche wurde deshalb von der reinen Nasenhöhe auf einen
3.4-mm-hohen Einführkanal bis zur Rabbet-Unterseite erweitert. Die Tasche
bleibt flach genug, gut entpulverbar und hat trotz stärkerem Haken noch
Restwand auf der X-Seite.

**Aktueller Baugruppen-Checker `v1.1.2`**:

- beste gefundene Hook-first-Lage: `-10°`, `dx = +0.40 mm`, `dz = +0.90 mm`
- eingehakte Lage kollisionsfrei (`max penetration = -0.089 mm`)
- vertikale Einfädelbahn kollisionsfrei
- Schliessbahn ohne harte Kollision; verbleibende Interferenz nur an den
  aktiven Schnappern (`snap ~1.03 mm`)

**STL-Heal-Status**:

- Direkte OCCT-STLs bleiben als Zwischenprodukt erhalten, werden aber nicht
  mehr als finale STL betrachtet.
- Neuer Pfad: STEP-Datei mit Gmsh zu STL remeshen, dann mit `pymeshfix`
  final reinigen.
- `trough.stl`: Gmsh-Remesh wasserdicht; `pymeshfix` reduziert
  12 Selbstdurchdringungen auf 0, Volumen 35.19 → 35.19 cm³.
- `lid.stl`: Gmsh-Remesh wasserdicht; `pymeshfix` reduziert
  32 Selbstdurchdringungen auf 0, Volumen 8.09 → 8.08 cm³.

**Verworfene Alternativen**:

- _Bei 62 mm bleiben_: nach Druckmuster-Fit unnötig konservativ, lässt
  nutzbaren Schachtquerschnitt ungenutzt.
- _X-Flansch über den Körper hinaus verbreitern_: würde die harte
  70-mm-Schachtöffnung unnötig riskieren. Der Flansch bleibt deshalb in X
  exakt auf Körperbreite.
- _Nur den Checker toleranter stellen_: hätte die reale Haken-Einfädelung
  nicht verbessert. Die höhere, weiterhin flache Tasche ist die robustere
  geometrische Lösung.
- _OCCT-STL direkt mit `pymeshfix.clean()` reparieren_: beim breiteren Trog
  destruktiv; die Reparatur hätte ~24 % Volumen entfernt. STEP→Gmsh liefert
  die bessere Ausgangstopologie.

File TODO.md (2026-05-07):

# TODO

## Offen

- [ ] `trough.stl` (geheilt) erneut beim Bureau hochladen und DFM-Check
      verifizieren (erwartet: 0 non-manifold, 0 Randkanten,
      0 Selbstdurchdringungen)
- [ ] Viewer-/Druckmuster-Recheck `v1.1.6`: fluchten die zwei +X-Slots mit den
      Schnappern, sitzt die einfache -X-Hakenleiste sauber in ihrer Tasche,
      und sind die internen Anti-Bauch-Bars beim Befüllen nicht störend?
- [ ] Fingergriff: reicht der 10 mm Y-Flanschüberstand, um die Kassette
      gegen den Sog der Absaugung zu ziehen? Prüfung nach Druckmuster.
- [ ] Armwurzel-Fillet visuell prüfen — Kanten-Selektor ist bbox-gefiltert,
      sollte jetzt robust greifen
- [ ] Probe-Einbau im Schacht: Flansch fängt an Oberkante/Unterkante? X passt
      ohne Anstehen durch die 70 mm Hartöffnung? Kassette steht die
      erwarteten 2.2 mm aus dem Schacht?
- [ ] Moosgummistreifen auf Y-Flächen des Körpers auswählen (Materialstärke
      auf Spalt ~2.5 mm zwischen Körper und harter Schachtwand abstimmen)
- [ ] Öffnungsbedienung am Druckmuster prüfen: reicht die mittige
      Ein-Finger-Hebebewegung an der Zuglippe? Lösen beide Schnapper sauber
      über die Auslöserampe? 1.1-mm-Lippen und 1.2-mm-Zuglippe MJF-sauber
      gedruckt?
- [ ] Passive Seite am Druckmuster prüfen: bleibt der -X-Haken beim Öffnen
      definiert eingehakt und klappt der Deckel tatsächlich um diese Seite
      auf? Reicht die kleine Verschiebebewegung zum kompletten Aushängen?
- [ ] Hook-first-Montage am Druckmuster plausibilisieren: lässt sich der
      Deckel ohne die alten passiven Eckfreistiche tatsächlich erst einhängen
      und dann herunterkippen?
- [ ] Top-Vlies am Druckmuster prüfen: passt das 3-mm-Filtervlies zwischen
      Anti-Bauch-Bars und Deckelunterseite in den 4.0-mm-Nominalspalt, ohne
      die Schnapper oder den Haken zu blockieren?
- [ ] Befülltest mit Granulat: bleiben die langen X-Wände durch die drei
      internen Bars sichtbar gerader, und hängen Pellets/Vlies nicht
      störend an den Bars?
- [ ] Maßprüfung nach Druck: Deckel-Spiel 0.30 mm in Ordnung? Hex-Lochweite
      im Soll (MJF-Verzug)?
- [ ] Druckorientierung mit Bureau abstimmen (Snap-Arme parallel zu
      Schichten, Flansch möglichst plan)
- [ ] FE-Abschätzung am Druckmuster plausibilisieren: subjektiv ~8–11 N
      Gesamt-Hebekraft? Wiederholtes Öffnen ohne Whitening/Rissbildung?
- [ ] Lüfter-Specs (Modell, Volumenstrom, Statikdruck) erfassen, um
      `size_z` ggf. nachzujustieren
- [ ] DFM-Check am Druckmuster: wirken die gefilleteten Kanten (Flansch-Step
      1.0 mm, Kavitätsboden 1.0 mm, Rabbet 0.3 mm) visuell / haptisch wie
      gewünscht? Sind die 4 offenen Flansch-Eckenschelfs (OCCT-Limitation)
      wirklich nur kosmetisch?
- [ ] Deckel-DFM am Druckmuster: Eckenfillet 1.0 mm, Oberkanten-Chamfer 0.5 mm,
      Unterkanten-Chamfer 0.2 mm / Zuglippen-Chamfer 0.4 mm haptisch ok?
      Stören die lokal scharfen Restkanten (OCCT-Limitation) beim Einsetzen?
- [ ] Optional v1.1.6: Flansch-Eckenschelfs durch Redesign (Flansch mit
      eigenen Ecken-Fillets) auflösen — nur falls das Druckmuster tatsächlich
      stört
- [ ] Lesbarkeit der Versionsgravur am Druckmuster prüfen — Font-Size 5 mm,
      Tiefe 0.6 mm ausreichend bei MJF/PA12? Ggf. Tiefe auf 0.8 mm erhöhen

## In Arbeit

_(leer)_

## Erledigt

- [x] Toolchain-Härtung: README-Sync-Checker, DFM-Alarme, FEM-Baseline-Diff,
      exakt gepinnte Dependencies (2026-05-07):
      - `scripts/check_readme_sync.py` (`./run check`) prüft 35 Parameter
        zwischen Script und README, mit Trailing-Zero- und
        Whitespace-Toleranz für deutschen Soft-Wrap
      - `scripts/fem_baseline_diff.py` (`./run fem-diff`) vergleicht die
        FEM-Outputs gegen unversionierte Baselines unter
        `output/FEM/baseline/`, mit `rel`/`abs`/`exact`-Modi und
        `--update-baseline` zum Promoten
      - `try_fillet`/`try_chamfer` nehmen jetzt `strict=True`; die
        README-DFM-Tabelle ist 1:1 als Annotation am Aufruf hinterlegt,
        und ein End-of-Build-Summary bricht den Lauf bei Regression ab
      - `requirements.txt` exakt gepinnt (build123d==0.10.0,
        cadquery-ocp==7.8.1.1.post1, ocp_vscode==3.3.4, …); OCCT-Minor
        ändert Fillet-Akzeptanz still
      - `.gitignore` entdoppelt
      - alle Toolings selbst smoke-getestet, Negativ-Pfade explizit
        verifiziert (DFM-Alarm-Trigger, FEM-Compare-Modi)

- [x] Release-Kandidat `v1.1.6` auf 95 mm Höhe, mehr Hex-Öffnungen und
      interne Anti-Bauch-Bars gebracht (2026-05-07):
      - `size_y` 93 → 95 mm, Flansch-Footprint jetzt 65 × 115 × 2.2 mm
      - Hex-Pattern 28 → 36 Löcher pro Seite durch `hex_margin_x` 4.0 → 2.8 mm
      - passive Deckel-Eckfreistiche entfernt; die sichtbare Diagonalkante auf
        den Druckteilen entfällt
      - drei interne Querbars bei `Y = -36, 0, +36 mm`, je 2.2 × 1.4 mm,
        mit 4.0 mm Nominalspalt zur Deckelunterseite für 3-mm-Obervlies
      - neuer Solver `fem/trough_bulge_fem.py` mit JSON, VTK und Heatmaps
      - Bulge-FEM bei 5 kPa: max. Ausbuchtung 0.083 → 0.023 mm, Druck für
        1.0 mm Ausbuchtung 60.5 → 217.8 kPa
      - Baugruppen-Checker bleibt kollisionsfrei; Hook-first-Montagepfad
        weiterhin plausibel
      - STEP/STL neu erzeugt; Trog und Deckel watertight und winding-consistent

- [x] Automatische Pip-/Venv-Umgebung ergänzt (2026-05-06):
      - `run` legt `.venv/` an und aktualisiert Abhängigkeiten aus
        `requirements.txt` nur bei Manifest-Änderung
      - Wrapper-Kommandos für CAD, lokale FEM, Baugruppenprüfung und
        Montagezeichnungen ergänzt
      - `pymeshfix` als optionale Heal-Abhängigkeit nach
        `requirements-heal.txt` ausgelagert

- [x] Aktive Schnapper moderat straffer gemacht (2026-05-06):
      - Version/Gravur auf `v1.1.3` angehoben
      - `hook_protr` 1.0 → 1.1 mm
      - lokale FEM: nominell ~10.3 N laterale Auslenkkraft pro Schnapper,
        ~10.4 N Gesamt-Hebekraft, FE-Band ~8.0–10.6 N
      - maximale Hauptdehnung ~3.4 %, weiterhin im PA12-`1/3`-Proxyband mit
        kleiner Reserve
      - Baugruppen-Checker bleibt kollisionsfrei; harte Restpenetration
        weiterhin 0 Punkte

- [x] Trogseitige Haken-Retentionslippe ergänzt (2026-05-06):
      - Version/Gravur auf `v1.1.5` angehoben
      - Haken-Tasche zweistufig: 1.35 mm tiefe Retentionstasche unten,
        0.55 mm tiefer Einführkanal oben
      - dadurch bleibt eine 0.80 mm tiefe Materiallippe in der Trogwand,
        unter der die Haken-Nase sichtbar trägt
      - äußerste Haken-Nase mit 0.2-mm-Fase entschärft
      - lokale Hook-FEM: PA12-`1/3`-Proxy-Haltekraft ~174–213 N
      - Baugruppen-Checker bleibt kollisionsfrei; harte Restpenetration
        weiterhin 0 Punkte

- [x] Passive Hakenleiste verstärkt und Haltekraft geprüft (2026-05-06):
      - Version/Gravur auf `v1.1.4` angehoben
      - realer Untergriff hinter der Trog-Innenwand 0.70 → 1.05 mm
      - Haken-Nase 0.35 mm über die Deckelkante nach außen gezogen
      - oberer Hakensteg 0.40 → 1.00 mm, Querschnitt 34 mm²
      - neuer Solver `fem/hook_hold_fem.py`
      - lokale Hook-FEM: PA12-`1/3`-Proxy-Haltekraft ~103–125 N
      - Baugruppen-Checker bleibt kollisionsfrei; harte Restpenetration
        weiterhin 0 Punkte

- [x] Breite nach Druckmuster-Fit auf 65 mm erhöht, Hook verstärkt und
      STEP-remesh-STLs ergänzt (2026-05-06):
      - `size_x` 62 → 65 mm, Flansch-Footprint jetzt 65 × 113 × 2.2 mm
      - Version/Gravur auf `v1.1.2` angehoben
      - passive Haken-Überdeckung 0.6 → 1.1 mm
      - passive Haken-Tasche auf 3.4 mm Höhe erweitert, damit der
        Hook-first-Checker mit der breiteren Baugruppe wieder kollisionsfrei
        bleibt
      - STL-Export auf STEP→Gmsh-Remesh plus `pymeshfix` umgestellt;
        `trough.stl` und `lid.stl` sind jetzt beide watertight mit 0
        gemeldeten Selbstdurchdringungen
      - STEP/STL und Montage-SVGs neu erzeugt

- [x] Release `v1.1.0` vorbereitet (2026-04-19):
      - asymmetrische Deckelverriegelung `1 einfache Hakenleiste + 2 Schnapper`
      - selbstlösende Schnapper mit oberer Auslöserampe
      - Zuglippe + Freistellung auf der Schnapper-Seite
      - Schnapperlänge 6.0 → 7.0 mm für geringere Öffnungskraft
      - Kraftabschätzung dokumentiert (~5.6–6.3 N lateral pro Schnapper,
        ~4.5 N Hebekraft gesamt)
      - `_heal_stl()` toleriert fehlendes `pymeshfix`

- [x] Lokale FEM für aktiven Schnapper ergänzt (2026-04-19):
      - neuer Solver `fem/snap_fit_fem.py`
      - Gmsh + scikit-fem Workflow
      - nominell ~9.5 N laterale Auslenkkraft pro Schnapper
      - nominell ~8.8 N Gesamt-Hebekraft, FE-Band ~6.7–9.0 N
      - maximale Hauptdehnung ~3.2 %

- [x] Vollbaugruppen-Kontaktmodell ergänzt (2026-04-19):
      - neuer Solver `fem/lid_trough_assembly.py`
      - voller Deckel gegen vollen Trog als starre STL-Baugruppe
      - Hook-first-Kinematik um passive Hakenlinie geprüft
      - passive `-X`-Eckfreistiche ergänzt und erneut geprüft
      - Hook-first-Kipp-/Einhakebahn im Suchraum jetzt geometrisch plausibel
      - harte Restkollision eliminiert; verbleibende Interferenz nur an den
        aktiven Schnappern als beabsichtigte elastische Einfederung

- [x] SVG-Montagezeichnungen ergänzt (2026-04-19):
      - neuer Generator `fem/assembly_sequence_svg.py`
      - Sequenzblatt für Einhängen → Herunterkippen → Einrasten
      - Detailblatt zur elastischen Schnapper-Einfederung

- [x] Dokumentation auf aktuellen `v1.1.0`-Stand synchronisiert (2026-04-19):
      - README beschreibt den aktualisierten Hook-first-Befund mit
        passiven Eckfreistichen als gültigen Stand
      - Beispielpfade für FEM-/Assembly-JSON und VTK dokumentiert
        inklusive Auto-Anlage der Zielverzeichnisse
      - SVG-Montagezeichnungen und Ausgabepfade dokumentiert
      - veraltete Kinematik-Blocker aus README/TODO bereinigt und nur noch als
        Zwischenstand im Logbuch eingeordnet

- [x] FreeCAD-Macro gelöscht, alle Referenzen entfernt (2026-04-17)
- [x] build123d-Script MJF-optimiert (2026-04-17):
      - Wände 1.8 → 2.2 mm
      - `fit_clear` 0.15 → 0.30 mm
      - Rabbet-Geometrie korrigiert (vorher 0.3 mm fragile Innenlippe)
      - Snap-Mechanik auf Durchbrüche in Aussenwand umgestellt
      - Armwurzel-Fillet 0.5 mm
      - Hex-Randabstand 3 → 4 mm
- [x] Material-Entscheidung PA11 (2026-04-17)
- [x] `hook_arm` auf 1.0 mm (2026-04-17)
- [x] CLAUDE.md, TODO.md, LOGBOOK.md angelegt (2026-04-17)
- [x] Schacht-Fit-Redesign (2026-04-18):
      - `size_x` 65 → 62 mm (1.5 mm Schaumstoff-Kompression pro Seite)
      - `size_y` 45 → 40 mm (ΔP-optimiert, ~30 mm Kohlebett, ~6 Mon.)
      - Snap-Durchbrüche nur an X-Seiten (Schaumstoff-Kontakt)
      - Fingermulde vorn oben (25 × 6 × 1.2 mm)
- [x] Grundlegende Umkonstruktion auf vertikalen Luftstrom (2026-04-18):
      - Hex jetzt auf Z-Flächen (Boden + Deckel), nicht mehr Y
      - Z (Luftstromachse) = 40 mm, Y (Schachthöhe) = 93 mm
      - Deckel ist abnehmbar und schnappt von oben auf
      - Einbaulage umgedreht: Deckel nach hinten, Boden nach vorne
      - Einschub-Stopper als Boden-Flansch, nur in Y verbreitert
        (62 × 103 × 2.2 mm), X bleibt ≤ 70 mm Hartöffnung
      - Moosgummi auf Y-Flächen für Axialabdichtung (user-applied)
      - Armwurzel-Fillet robust per bbox-Filter
- [x] Nach erstem Viewer-Check (2026-04-18):
      - Snap-Slot -X: Offset-Vorzeichen korrigiert, schneidet jetzt sauber
        durch beide X-Wände
      - Fingermulde entfernt (ergonomisch sinnlos); Fingergriff übernimmt
        der Y-Flanschüberstand
      - Hex-Raster 8 → 10 mm flats (48 % Offenfläche, Web 1.2 mm, Margin
        4 mm unverändert)
      - Flanschüberstand Y 5 → 10 mm (besserer Fingergriff, Flansch
        62 × 113 × 2.2 mm)
- [x] git init, Root-Commit, Tag `v1.0.0` (2026-04-18)
- [x] Output-Reorganisation `output/STEP/` + `output/STL/`, destruktiv in
      v1.0.0 eingefaltet (2026-04-18)
- [x] Versionsgravur v1.0.1 auf +Y-Flanschüberstand (2026-04-18):
      Font-Size 5 mm, 0.6 mm tief, Arial, Position auf Z=0-Fläche des
      Flansches; `VERSION`-Konstante im Script-Header. Gravur-Ebene
      gespiegelt (x_dir=-X, z_dir=-Z, y_dir=+Y) damit der Text aus der
      Apartment-Sichtrichtung (-Z) korrekt lesbar ist.
- [x] STL-Mesh-Heal (2026-04-18):
      - `pymeshfix` als Dependency; Post-Export-Schritt `_heal_stl`
      - Trough: 1 Randloop + 296 Selbstdurchdringungen → **0 / 0** (clean)
      - Lid: abort — Heal würde Volumen von 7.25 → 0.04 cm³ zerstören
        (Selbstdurchdringungen sind bei hex-perforierter Platte
        topologisch fundamental, nicht reparierbar ohne Komponentenverlust)
      - Volumen-Wächter (≤ 5 % Abnahme) behält bei Fehler das Original
      - Bureau-Test (2026-04-18): `lid.stl` ungeheilt akzeptiert, Auto-Heal
        kommt mit den 83 Selbstdurchdringungen klar
- [x] Deckel-DFM (2026-04-18):
      - `lid_corner_fil` 1.0 mm (4 vertikale Ecken, Handling)
      - `lid_top_cham` 0.5 mm (4 Oberkanten, Absplitterschutz)
      - `lid_bot_cham` 0.2 mm (Rabbet-Einführschräge) — 2/4 Kanten (Y-Seiten)
        angenommen; 2 X-Seiten-Kanten OCCT-verweigert wegen Nähe zur
        Armwurzel­fillet, bleiben scharf (nicht handgriffrelevant)
      - Reihenfolge: Chamfers vor Eckenfillet (Topologie-Konsistenz)
- [x] DFM-Optimierung (2026-04-18):
      - `try_fillet` / `try_chamfer` mit Per-Kanten-Fallback bei
        OCCT-Konflikten
      - Flansch-Unterseite 4 Chamfer 0.8 mm (Handling)
      - Flansch-Y-Step 2 gerade Kanten Fillet 1.0 mm (Kerbspannung)
      - Flansch-Eckenschelfs 4 Bögen: Fillet und Chamfer verweigert von
        OCCT (Tangentenkonflikt mit 2-mm-Körperecken­fillet) — akzeptiert
        als kosmetische Limitation
      - Kavitäts-Bodeninnenkanten 4 Fillet 1.0 mm (Kerbspannung + Entpulvern)
      - Rabbet-Schulterkanten Fillet 0.3 mm (weicher Step, Schulter bleibt
        mindestens 0.7 mm breit)
      - `hook_protr` 0.45 → 0.50 mm (MJF-min. positives Feature;
        Armdehnung 3.12 % → 3.33 %, weiterhin <5 % Fliessgrenze)

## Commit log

2026-04-17 v1.0.0 — Aktivkohlefilter-Kassette für MJF/PA11
    Parametrisches build123d-Design eines zweiteiligen Filtereinsatzes
    (Trog + Deckel) für Fensterschacht-Lüftung mit aktiven Absaugungen.
    - Vertikaler Luftstrom durch Hex-Perforation (10 mm flats) auf Boden
    und Deckel, ~48 % Offenfläche
    - Abmessungen 62 × 93 × 40 mm, Kohlebett 29.3 mm, ~78 g/Kassette
    - Boden-Flansch 62 × 113 × 2.2 mm als Einschub-Stopper und Fingergriff
    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
    [lid.step, lid.stl, trough.step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]
2026-04-18 v1.0.2 — DFM-Optimierung, Versionsgravur, STL-Mesh-Heal
    Sammelrelease der Arbeit seit v1.0.0:
    - Versionsgravur auf +Y-Flanschüberstand (5 mm Font, 0.6 mm tief,
    Plane-Spiegelungs-Fix für Apartment-Sichtrichtung)
    - DFM-Radien am Trog: Flansch-Fasen/Fillets, Kavitätsboden,
    Rabbet-Schulter, Per-Kanten-Fallback für OCCT-Grenzfälle
    - Deckel-DFM: Eckenfillet 1.0 mm, Ober-Chamfer 0.5 mm,
    Unter-Chamfer 0.2 mm (2/4, X-Seiten OCCT-verweigert)
    - pymeshfix-Post-Processing nach STL-Export (Trough 0 Randloops /
    0 Selbstdurchdringungen nach Heal; Lid-Volumen-Wächter schützt
    vor destruktiver Heal-Kaskade bei hex-perforierter Topologie)
    Upload-Status bestätigt beim MJF-Bureau: trough.stl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
    [lid.step, lid.stl, trough.step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]
2026-04-19 Release v1.1.0
    [lid.step, lid.stl, trough.step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]
2026-05-06 Strengthen hook receiver and add FEM checks
    [lid.step, lid.stl, trough.step]
2026-05-06 Release v1.1.6 body and anti-bulge update
    [lid.step, lid.stl, trough.step]
2026-05-07 Toolchain hardening: README sync check, DFM alarms, FEM baseline diff
    - scripts/check_readme_sync.py (./run check) verifies 35 geometry and
    version constants between carbon_filter_build123d.py and README.md
    - scripts/fem_baseline_diff.py (./run fem-diff) compares FEM-solver
    outputs against output/FEM/baseline/ with per-field thresholds;
    --update-baseline promotes a new release after deliberate change
    - try_fillet / try_chamfer gain strict=True; the build aborts if a
    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
    [lid.step, trough.step]
